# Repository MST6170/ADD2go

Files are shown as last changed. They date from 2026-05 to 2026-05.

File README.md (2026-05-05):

# ADD2go

**Wireless Fernanzeige für Dinamica Generale ADD2 / Siloking Mischwagen**

Überträgt Gewichtsdaten kabellos von der Mischwagen-Waage zum Radlader-Display oder Smartphone.

ADD2go ist in erster Linie eine **Fernanzeige** für die ADD2 Waage. Zusätzlich integriert ist eine **Schaufel-Wiegung** mit Drucksensor — fand ich nützlich, daher ist sie mit reingewandert.

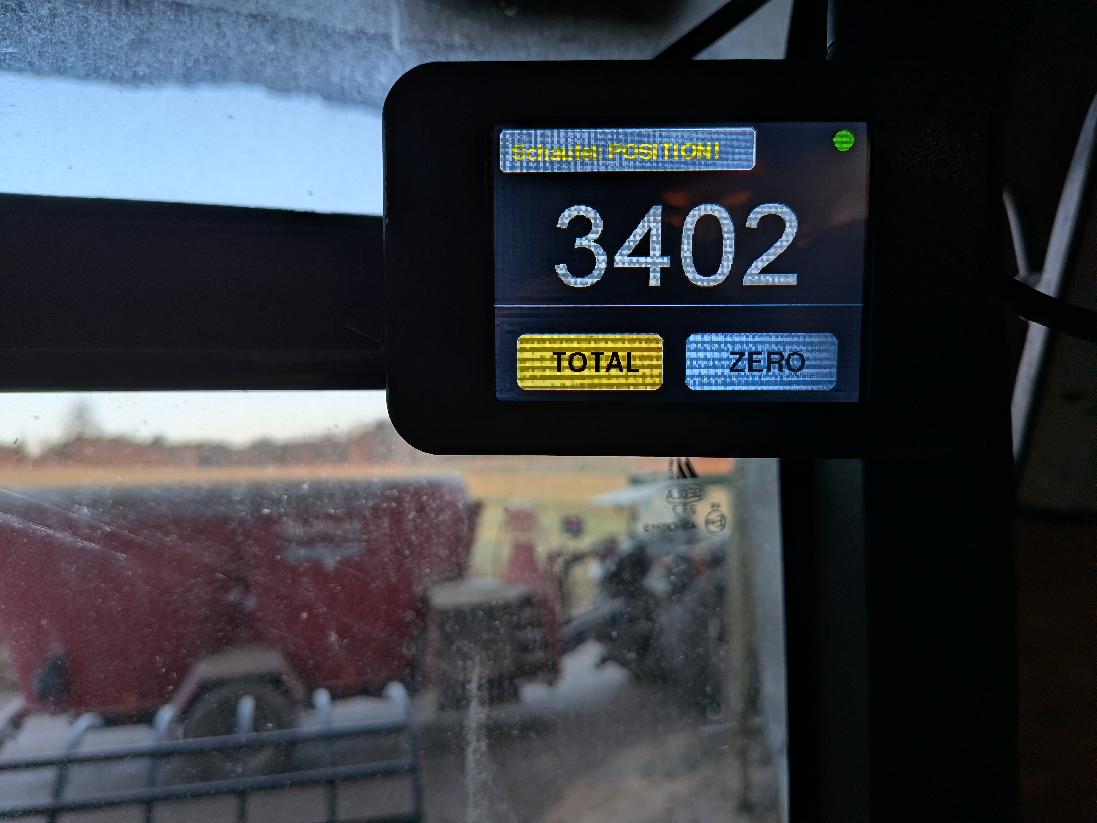
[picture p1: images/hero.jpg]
ADD2go

*ADD2go — kabellose Fernanzeige für die ADD2-Waage*






---

## 📋 Übersicht

ADD2go besteht aus zwei ESP32-Modulen und einer optionalen WebApp:

| Modul | Standort | Funktion |
|---|---|---|
| **Sender** | Mischwagen | Liest RS232 von ADD2 Waage, sendet per WiFi |
| **Empfänger** | Radlader | Zeigt Gewicht auf TFT-Display an |
| **WebApp** | Smartphone | Gewicht im Browser anzeigen |

> 💡 **Hinweis zur Hardware:** Sender und Empfänger nutzen **dieselbe Platine** — sie wird je nach Anwendung unterschiedlich bestückt (Sender: MAX3232 + WI-NET; Empfänger: zusätzlich TFT-Header, ADS1115-Header, K7812M für Drucksensor). Details siehe [`add2go_pcb/README.md`](add2go_pcb/README.md).

### Features

**Sender:**
- ✅ RS232 Auswertung des ADD2 Protokolls
- ✅ WiFi Access Point ("ADD2go")
- ✅ WiFi-Manager - zusätzlich mit Heimnetz verbinden
- ✅ mDNS - erreichbar unter `http://add2go.local`
- ✅ UDP Broadcast für Hardware-Empfänger
- ✅ WebSocket Server für WebApp
- ✅ Eingebaute WebApp mit TOTAL/ZERO Funktion
- ✅ "OFF" Erkennung wenn Waage ausgeschaltet
- ✅ Hardware Watchdog (kein Aufhängen)

**Empfänger:**
- ✅ Echtzeit-Gewichtsanzeige
- ✅ TOTAL/ZERO Funktion (Auto-Reset bei Verbindungsverlust)
- ✅ Schaufel-Wiegung mit Drucksensor (optional)
- ✅ Filter für stabile Anzeige (Mittelwert + Hysterese)
- ✅ ADS1115-Watchdog (Sensor-Ausfall wird erkannt)
- ✅ Auto-Reconnect bei WiFi-Verlust
- ✅ Hardware Watchdog

---

## 🌐 WiFi-Manager

Der Sender kann sich zusätzlich mit einem externen WLAN (z.B. Hof-WLAN) verbinden. Dadurch muss das Handy nicht mehr ins "ADD2go" WLAN wechseln.

### Einrichtung

1. Handy mit WLAN **"ADD2go"** verbinden
2. Browser öffnen: `http://192.168.4.1/setup`
3. Verfügbare Netzwerke werden angezeigt
4. Netzwerk auswählen, Passwort eingeben
5. Nach erfolgreicher Verbindung: erreichbar unter `http://add2go.local`

### Betriebsmodi

| Modus | Beschreibung |
|---|---|
| **Nur AP** | Standard - Sender erstellt eigenes WLAN "ADD2go" |
| **AP + Station** | Sender ist zusätzlich mit Heimnetz verbunden |

### Vorteile der Heimnetz-Verbindung

- Kein WLAN-Wechsel mehr nötig am Handy
- Erreichbar unter `http://add2go.local` (mDNS)
- WLAN-Daten werden gespeichert (überlebt Neustart)
- Auto-Reconnect wenn Mischwagen zurückkommt
- AP "ADD2go" bleibt zusätzlich aktiv (Fallback)

---

## 🔧 Hardware

### Sender (Mischwagen)

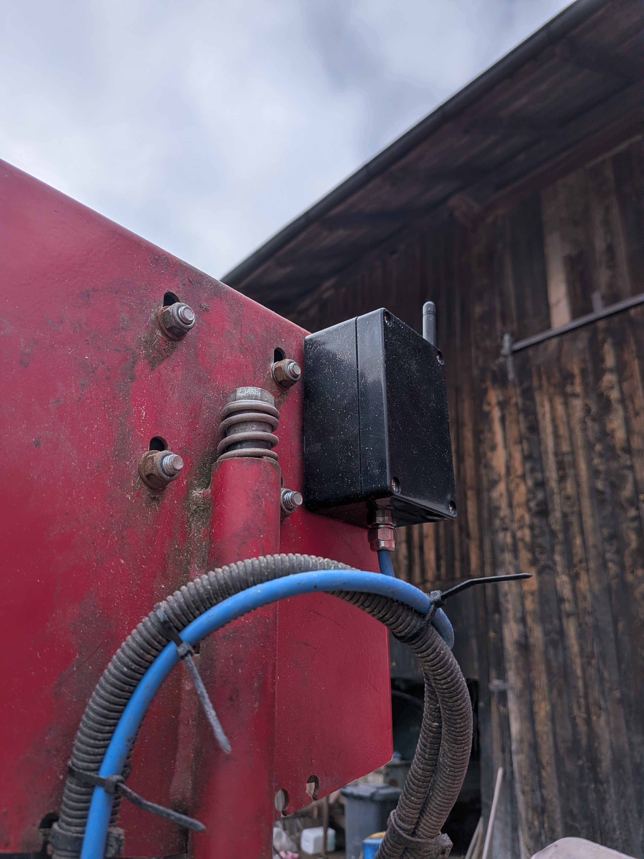
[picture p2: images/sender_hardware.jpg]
Sender-Modul

*Sender-Modul: ESP32, MAX3232 (RS232) und 7805-Spannungsregler*

| Komponente | Typ | Bemerkung |
|---|-----|---|
| Mikrocontroller | [ESP32-WROOM-32U](https://www.amazon.de/dp/B0F65KPWYR) | Mit U.FL Antennenanschluss |
| Antenne | 2.4GHz extern | Im ESP32-Set enthalten |
| RS232 Wandler | MAX3232CPE | DIP-16, 5x 1µF Kondensatoren |
| Spannungsregler | K7805M | 12V → 5V Schaltregler (pin-kompatibel zu 7805, kein Kühlkörper nötig) |
| Verpolschutz | 1N5822 | Schottky-Diode |
| Überspannungsschutz | 1.5KE18A | TVS-Diode 18V |
| WI-NET Stecker | Binder M16 5-pol | Bestellnr. 09 0313 00 05 |
| Gehäuse | [Industrie-Gehäuse 100×68×50 mm](https://de.aliexpress.com/item/1005005622148025.html) | gekauft (kein 3D-Druck nötig) |
| Platine | Custom KiCad-Projekt | Schaltplan, Layout, Fertigung — siehe [`add2go_pcb/README.md`](add2go_pcb/README.md) |

**Pinbelegung Sender:**

| ESP32 Pin | Funktion |
|---|---|
| GPIO16 | RX2 ← MAX3232 (Daten von Waage) |
| GPIO17 | TX2 → MAX3232 (nicht verwendet) |
| 5V | Versorgung vom Spannungsregler |
| GND | Gemeinsame Masse |

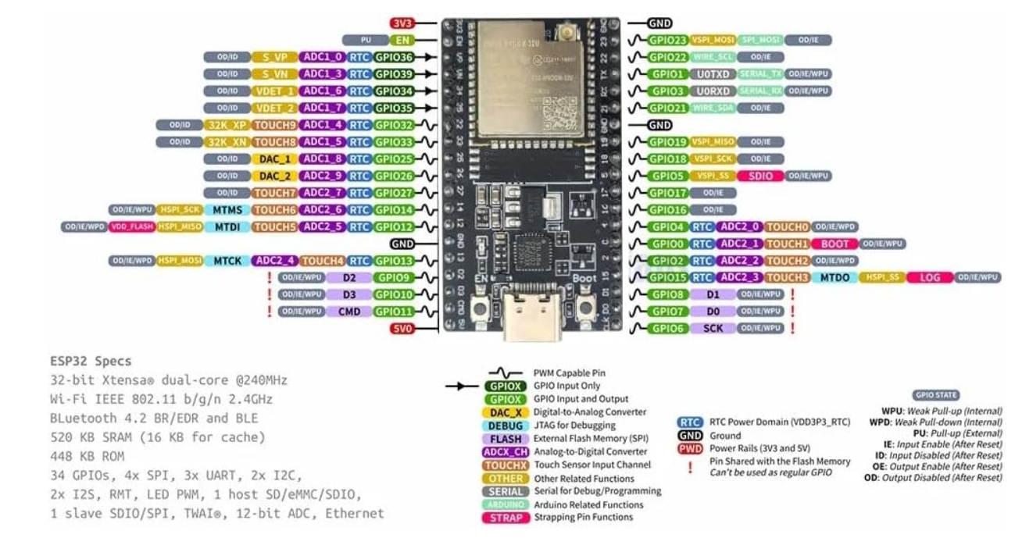
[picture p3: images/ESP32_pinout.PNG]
ESP32 Pinout

*ESP32-WROOM-32 Pinbelegung (Referenz)*

### Empfänger (Radlader)

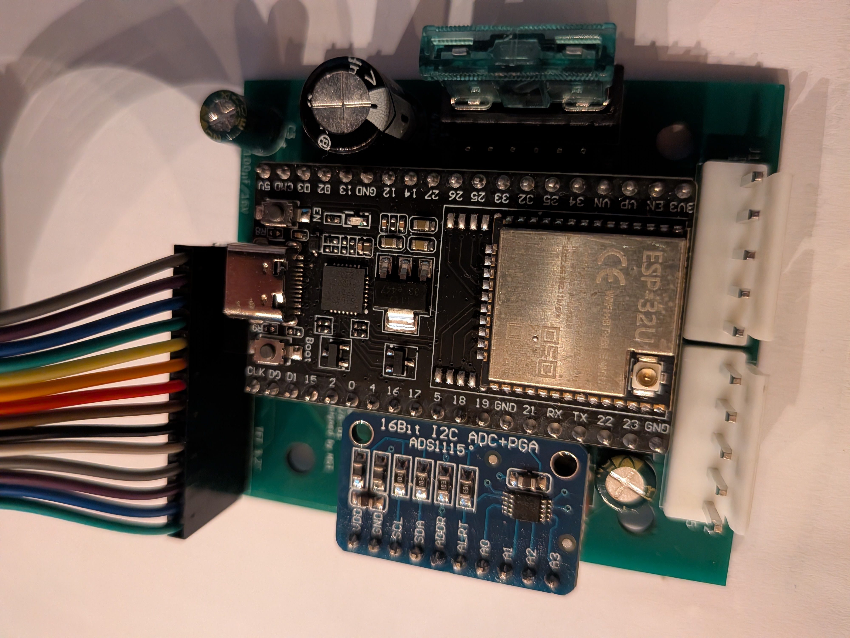
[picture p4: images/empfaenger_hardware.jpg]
Empfänger-Modul

*Empfänger-Modul: ESP32, ILI9341 Display mit Touch und ADS1115 ADC*

| Komponente | Typ | Bemerkung |
|---|-----|---|
| Mikrocontroller | [ESP32-WROOM-32U](https://www.amazon.de/dp/B0F65KPWYR) | Mit U.FL Antennenanschluss |
| Antenne | 2.4GHz extern | Im ESP32-Set enthalten |
| Display | [ILI9341 3.2" TFT](https://de.aliexpress.com/item/1005003005216533.html) | 320x240, SPI, mit Touch |
| Touch | XPT2046 | Resistiv, im Display integriert |
| ADC | ADS1115 | 16-bit, I²C (für Schaufel-Wiegung) |
| Drucksensor | [XIDIBEI 0-300 bar](https://de.aliexpress.com/item/4001002862246.html) | 9-36V Versorgung, 0.5-4.5V Ausgang (für Schaufel-Wiegung, optional) |
| Reed-Kontakt | Digital | Wiegeposition erkennen (optional) |
| Spannungsregler 5 V | K7805M | 12 V → 5 V Schaltregler (für ESP32) |
| Spannungsregler 12 V | K7812M | stabilisierte 12 V (für Drucksensor) |
| Gehäuse | 3D-gedruckt | STL-Dateien, Schalter, Kabelverschraubung — siehe [`case/README.md`](case/README.md) |
| Platine | Custom KiCad-Projekt | Schaltplan, Layout, Fertigung — siehe [`add2go_pcb/README.md`](add2go_pcb/README.md) |

**Pinbelegung Empfänger:**

| ESP32 Pin | Funktion |
|---|---|
| GPIO5 | Display CS |
| GPIO2 | Display RST |
| GPIO4 | Display DC |
| GPIO23 | SPI MOSI |
| GPIO18 | SPI SCK |
| GPIO19 | SPI MISO |
| GPIO15 | Touch CS |
| GPIO14 | Touch IRQ |
| GPIO21 | I²C SDA (ADS1115) |
| GPIO22 | I²C SCL (ADS1115) |
| GPIO36 | Reed-Kontakt (LOW = Wiegeposition) |

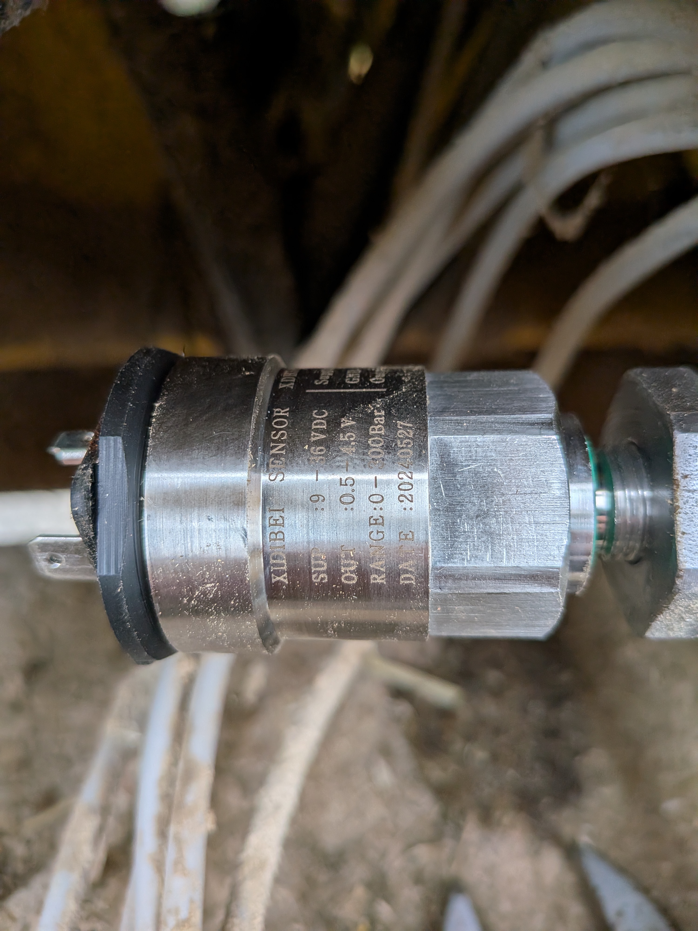
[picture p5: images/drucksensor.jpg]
XIDIBEI Drucksensor

*XIDIBEI Drucksensor (0–300 bar, 9–36 V → 0,5–4,5 V) — Quelle für die Schaufel-Wiegung*

### WI-NET Stecker (ADD2 Waage)

Der WI-NET Anschluss ist ein 5-poliger M16 Stecker an der ADD2 Waage.

**Passender Kabelstecker:** [Binder Serie 680, M16, 5-polig](https://www.binder-connector.de/de/produkte/rundsteckverbinder/m16-ip40-serie-680/kabelstecker-09-0313-00-05)
- Bestellnummer: **09 0313 00 05**
- Lötkontakte, 3.0-6.0mm Kabeldurchlass

> 💡 **Hinweis:** Bei diesem Stecker bin ich mir nicht 100% sicher — er passt nicht ganz exakt in die Buchse, funktioniert aber zuverlässig.

Die Pinbelegung wurde durch eigene Messungen ermittelt:

| Pin | Position | Funktion | Verbindung |
|-----|---|---|---|
| 1 | unten | +12V | → Spannungsregler VIN |
| 2 | rechts oben | GND | → Gemeinsame Masse |
| 3 | oben mitte | TX | → MAX3232 R1IN (Pin 13) |
| 4 | links oben | - | nicht belegt |
| 5 | links unten | - | nicht belegt |

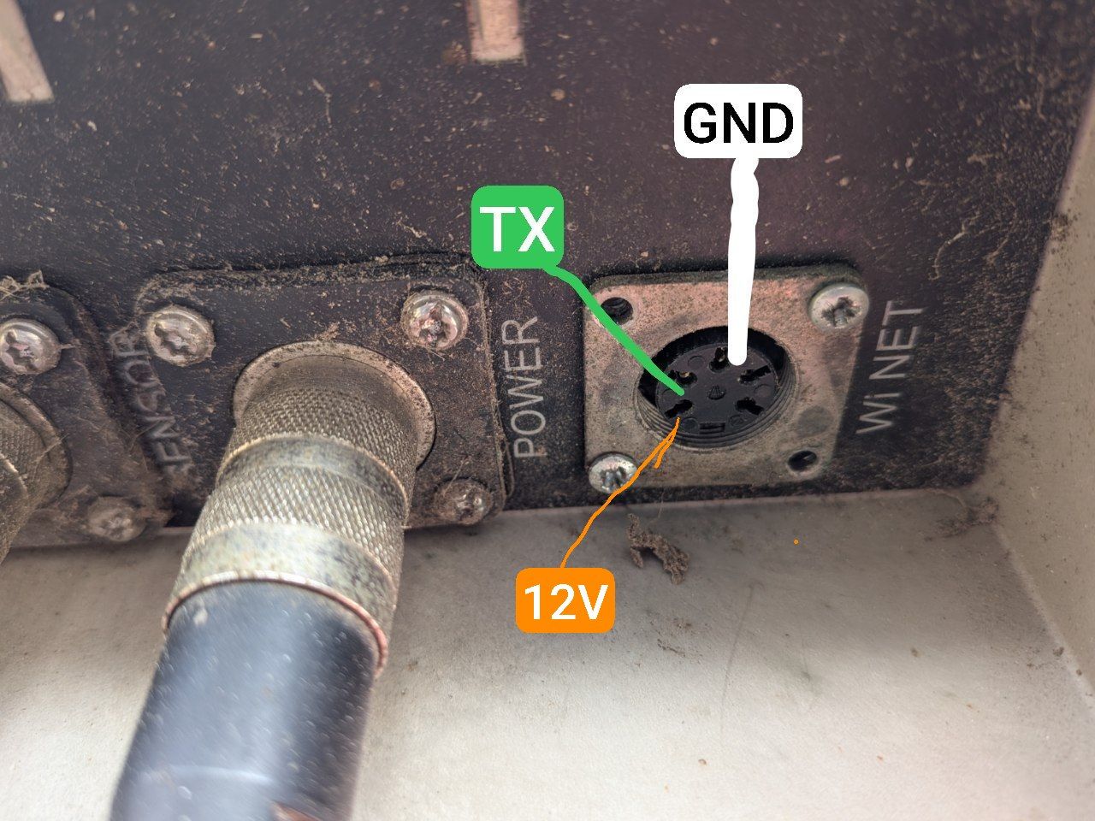
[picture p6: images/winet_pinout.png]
WI-NET Stecker

*WI-NET Stecker (Binder M16, 5-polig) — eigene Messung der Pinbelegung*

> ⚠️ **Wichtig:** Pinbelegung von vorne auf die Buchse (an der Waage) gesehen!

---

## 📡 Kommunikation

### WiFi Konfiguration

| Parameter | Wert |
|---|---|
| AP SSID | `ADD2go` |
| AP Passwort | keins (offen) |
| AP IP | `192.168.4.1` |
| AP Subnetz | `255.255.255.0` |
| mDNS Hostname | `add2go.local` |
| WiFi Modus | APSTA (AP + Station gleichzeitig) |

### Netzwerk-Protokolle

| Protokoll | Port | Richtung | Verwendung |
|---|---|---|---|
| UDP Broadcast | 5005 | Sender → Empfänger | Hardware-Display |
| WebSocket | 81 | Sender ↔ Browser | WebApp (bidirektional) |
| HTTP | 80 | Browser → Sender | WebApp + Setup-Seite |

### UDP Protokoll (für Hardware-Empfänger)

Der Sender sendet alle 100ms (10 Hz) einen UDP-Broadcast:

| Parameter | Wert |
|---|---|
| Ziel-IP | `192.168.4.255` (Broadcast) |
| Port | `5005` |
| Format | ASCII String |

**Nachrichten:**

| Nachricht | Bedeutung |
|---|---|
| `1234` | Gewicht in kg (ohne Einheit) |
| `OFF` | Waage ist ausgeschaltet |

### WebSocket Protokoll (für WebApp)

Der Sender sendet alle 100ms (10 Hz) an alle verbundenen WebSocket-Clients:

| Parameter | Wert |
|---|---|
| Port | `81` |
| Format | `Gewicht\|RSSI` |

**Beispiele:**

| Nachricht | Bedeutung |
|---|---|
| `1234\|-65` | 1234 kg, Signalstärke -65 dBm |
| `OFF\|-70` | Waage aus, Signalstärke -70 dBm |

---

## 📟 RS232 Protokoll (ADD2 Waage)

Das RS232 Protokoll wurde durch eigenes Reverse-Engineering ermittelt.

### Schnittstellenparameter

| Parameter | Wert |
|---|---|
| Baudrate | 19200 |
| Datenbits | 8 |
| Parität | Keine |
| Stoppbits | 1 |
| Updaterate | ~1.3 Hz (alle ~770ms) |

### Frame-Struktur

Die Waage sendet kontinuierlich Frames mit folgendem Aufbau:

```
[Präambel] [Start] [Type] [Seq] [Header] [Gewicht ASCII] [Ende]
    16       0x23   0x03   xx    0x18 0x00    "  1234"     0x0A
```

| Feld | Bytes | Wert | Beschreibung |
|---|---|---|---|
| Präambel | 16 | variabel | Sync-Bytes (werden ignoriert) |
| Start | 1 | `0x23` | Start-Marker (`#`) |
| Type | 1 | `0x03` | Frame-Typ (ETX) |
| Sequence | 1 | `0x00-0xFF` | Laufender Zähler |
| Header | 2 | `0x18 0x00` | Fester Header |
| Gewicht | variabel | ASCII | Rechtsbündig mit Leerzeichen |
| Ende | 1 | `0x0A` | Line Feed (LF) |

### Beispiel-Frame

```
Hex:  23 03 7B 18 00 20 20 20 20 32 0A
      │  │  │  │  │  └──────────┴──┴── "    2" + LF = 2 kg
      │  │  │  └──┴── Header 0x18 0x00
      │  │  └── Sequence 0x7B (123)
      │  └── Type 0x03
      └── Start 0x23
```

### Gewichtswerte

| Anzeige Waage | RS232 Daten | Bedeutung |
|---|---|---|
| `2` | `20 20 20 20 32` | 2 kg |
| `123` | `20 20 31 32 33` | 123 kg |
| `1234` | `20 31 32 33 34` | 1234 kg |
| (aus) | keine Daten | Waage ausgeschaltet |

### OFF-Erkennung

Wenn 3 Sekunden lang keine gültigen RS232-Daten empfangen werden, gilt die Waage als ausgeschaltet. Der Sender sendet dann `"OFF"` über UDP und WebSocket.

---

## 💾 Installation

### Voraussetzungen

- Arduino IDE 1.8.19
- ESP32 Board Package (v3.x empfohlen)
- USB-Treiber für ESP32 (CP2102 oder CH340)

### Benötigte Libraries

**Sender:**
- WebSockets by Markus Sattler (Library Manager: "WebSockets")

**Empfänger:**
- TFT_eSPI by Bodmer
- XPT2046_Touchscreen by Paul Stoffregen
- Adafruit ADS1X15 by Adafruit

### TFT_eSPI Konfiguration

Die TFT_eSPI Library muss für das ILI9341 Display konfiguriert werden.

> ⚠️ **Wichtig:** Die TFT_eSPI Library hat eine **globale** Konfigurationsdatei (`User_Setup.h`). Diese wird von ALLEN Projekten geteilt, die TFT_eSPI verwenden! Wenn du an einem anderen Projekt arbeitest und die Pins änderst, läuft ADD2go nicht mehr — `tft.init()` hängt dann beim Boot ohne Fehlermeldung. **Daher: vor jedem Flashen prüfen, dass `User_Setup.h` zu ADD2go passt.**

**Datei:** `Arduino/libraries/TFT_eSPI/User_Setup.h`

```cpp
// Display-Treiber
#define ILI9341_DRIVER

// Display-Größe
#define TFT_WIDTH  240
#define TFT_HEIGHT 320

// Pin-Definitionen
#define TFT_CS   5
#define TFT_DC   4
#define TFT_RST  2
#define TFT_MOSI 23
#define TFT_SCLK 18
#define TFT_MISO 19

// SPI-Geschwindigkeit
#define SPI_FREQUENCY 40000000

// Touch
#define TOUCH_CS 15
```

### Flashen

**Sender:**
```
Board:     ESP32 Dev Module
Datei:     add2go_sender_v1_2_4/add2go_sender_v1_2_4.ino
Baudrate:  115200
```

**Empfänger:**
```
Board:     ESP32 Dev Module
Datei:     add2go_empfaenger_v1_0_2/add2go_empfaenger_v1_0_2.ino
Baudrate:  115200
```

---

## 🖥️ Bedienung

### Hardware-Display (Empfänger)

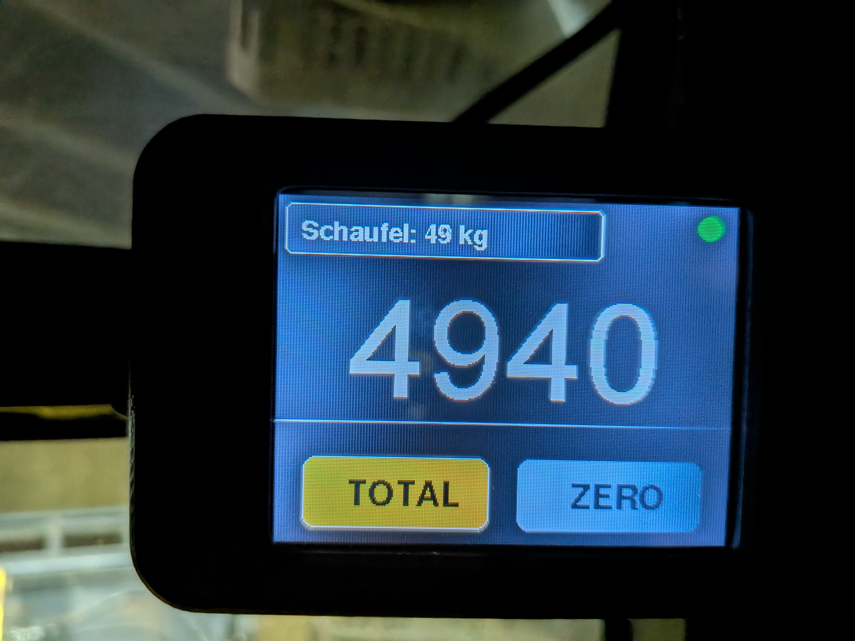
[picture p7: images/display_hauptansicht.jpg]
Display Hauptansicht

*Hauptansicht mit Gewichtszahl und TOTAL/ZERO-Buttons*

**Anzeigen:**

| Anzeige | Farbe | Bedeutung |
|---|---|---|
| Gewicht | Weiß | Normale Anzeige |
| `OFF` | Rot | Waage ausgeschaltet |
| `OFFLINE` | Rot | Keine WiFi-Verbindung zum Sender |
| `SUCHE..` | Orange | WiFi wird gesucht |
| `- - - -` | Grau | Verbunden, warte auf Daten |

**Buttons:**

| Button | Funktion |
|---|---|
| **TOTAL** | Zeigt Gesamt-Gewicht von Waage |
| **ZERO** | Setzt aktuelles Gewicht als Null (Differenz-Messung) |
| **Schaufel** | Öffnet Schaufel-Wiegung Menü |

> 💡 **Hinweis:** ZERO wird automatisch zurückgesetzt wenn die Verbindung zum Sender verloren geht oder die Waage auf OFF wechselt. So gibt es nach Wiedereinschalten keinen falschen Offset.

**Schaufel-Wiegung Menü:**

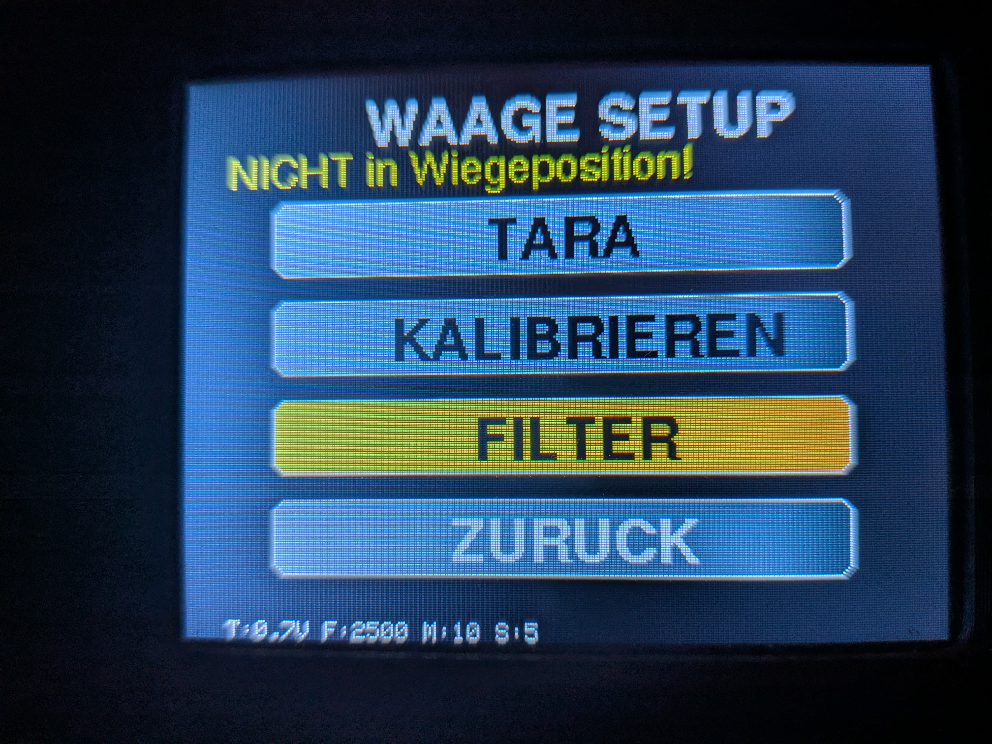
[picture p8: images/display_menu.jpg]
Schaufel-Wiegung Menü

*Setup-Menü für die Schaufel-Wiegung*

| Menüpunkt | Funktion |
|---|---|
| TARA | Setzt leere Schaufel als Nullpunkt |
| KALIBRIEREN | Bekanntes Gewicht eingeben zur Kalibrierung |
| FILTER | Mittelwert-Anzahl (5-30) und Hysterese-Schwelle (1-10 kg) |
| ZURÜCK | Zurück zur Hauptansicht |

> 💡 **Hinweis:** Bei TARA und Kalibrierung wird der Filter-Buffer automatisch geleert, damit die Anzeige sofort die neuen Werte zeigt.

**Sensor-Ausfall:** Wenn der ADS1115 nicht antwortet (z.B. Kabelbruch, Wackelkontakt), zeigt der Schaufel-Button `SENSOR-FEHLER` in rot an. TARA und KALIBRIEREN sind dann gesperrt.

---

## 📱 WebApp

Der Sender bietet eine eingebaute WebApp - das Gewicht direkt auf dem Smartphone anzeigen. Sie funktioniert parallel zum Hardware-Empfänger und ist als Nebenfunktion gedacht.

<p align="center">
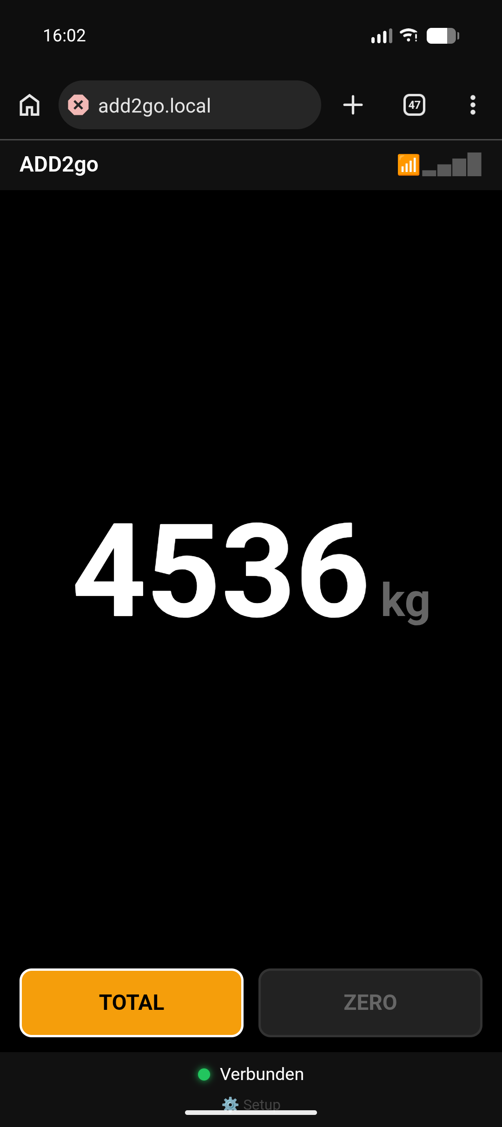
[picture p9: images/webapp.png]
WebApp am Smartphone
  
  <br>
  <em>WebApp im Browser am Smartphone</em>
</p>

### Zugriff

| Methode | URL | Wann nutzen |
|---|-----|---|
| Direkt | `http://192.168.4.1` | Handy mit "ADD2go" WLAN verbunden |
| Heimnetz | `http://add2go.local` | Handy im Hof-WLAN (nach Setup) |
| Heimnetz | `http://[IP-Adresse]` | Falls mDNS nicht funktioniert |

### Funktionen

| Element | Beschreibung |
|---|---|
| **Gewichtsanzeige** | Groß und zentral, mit "kg" Einheit |
| **TOTAL** | Zeigt Gesamtgewicht von der Waage |
| **ZERO** | Speichert aktuelles Gewicht, zeigt Differenz |
| **Signalstärke** | 📶▂▄▆█ (4 Stufen) |
| **Status** | 🟢 Verbunden / 🟠 Waage aus / 🔴 Offline |

### TOTAL / ZERO Funktion

- **TOTAL**: Normaler Modus - zeigt das Gewicht wie es von der Waage kommt
- **ZERO**: Drücken um aktuelles Gewicht als Nullpunkt zu setzen. Danach wird die Differenz angezeigt. Praktisch zum Wiegen von Zuladungen.

Der aktive Modus ist **orange** markiert. Diese Funktion läuft lokal in der WebApp und beeinflusst nicht die ADD2 Waage selbst.

---

## 🔍 Troubleshooting

### Häufige Probleme

| Problem | Ursache | Lösung |
|---|---|---|
| Boot-Loop, hängt bei `tft.init()` | Falsches `User_Setup.h` (z.B. von anderem Projekt überschrieben) | `User_Setup.h` der TFT_eSPI Library prüfen, Pins müssen zu ADD2go passen |
| Display zeigt `OFFLINE` | Kein WiFi zum Sender | Sender einschalten, Nähe prüfen, Antennen prüfen |
| Display zeigt `OFF` | Waage ausgeschaltet | ADD2 Waage einschalten |
| Display zeigt `- - - -` | WiFi ok, aber keine Daten | RS232 Verkabelung prüfen |
| Schaufel: `SENSOR-FEHLER` | ADS1115 antwortet nicht | I²C Verkabelung prüfen, Neustart |
| WebApp zeigt `---` | WebSocket nicht verbunden | Seite neu laden, WLAN prüfen |
| WebApp Buttons grau | Keine Verbindung | Warten oder Seite neu laden |
| `add2go.local` geht nicht | mDNS Problem | IP-Adresse direkt verwenden |
| WLAN-Daten nicht gespeichert | NVS Fehler | Serial Monitor prüfen |
| Sender startet neu | Watchdog | Serial Monitor auf Fehler prüfen |

### Serial Monitor Debug

Baudrate: **115200**

**Sender Startup (normal):**
```
========================================
ADD2go Sender - v1.2.4
========================================

[NVS] Lade gespeicherte Daten...
[NVS] SSID: MeinHofWLAN
[NVS] Passwort: (gespeichert)
[NVS] Auto-Connect: JA
[OK] RS232 gestartet (19200 Baud, GPIO16)
[OK] Watchdog: 10 Sekunden
[OK] WiFi AP gestartet: ADD2go
[OK] AP IP: 192.168.4.1
[STA] Verbinde mit: MeinHofWLAN
....
[STA] Verbunden! IP: 192.168.1.38
[OK] mDNS: http://add2go.local
[OK] UDP Port: 5005
[OK] WebServer gestartet (Port 80)
[OK] WebSocket gestartet (Port 81)

=========== ZUGRIFF ===========
Im ADD2go WLAN:
  WebApp:  http://192.168.4.1
  Setup:   http://192.168.4.1/setup

Im Heimnetz (mDNS):
  WebApp:  http://add2go.local
  Setup:   http://add2go.local/setup
  oder:    http://192.168.1.38
===============================

Warte auf ADD2 Waage...
```

**Sender Betrieb:**
```
[RS232] Gewicht: 1234 kg
[UDP] Gesendet: "1234" (1 AP Clients)
[WS] Client #0 verbunden
[STATUS] AP Clients: 1 | WS Clients: 1 | STA: MeinHofWLAN (192.168.1.38)
```

**Empfänger Startup:**
```
========================================
ADD2go Empfaenger - v1.0.1
========================================

[OK] Reed-Kontakt GPIO36 konfiguriert
[OK] ADS1115 gefunden
[OK] NVS geladen - Tara: 0.500V, Faktor: 100.0 kg/V
[OK] Display initialisiert
[OK] Touch initialisiert
[OK] Watchdog: 5 Sekunden
[OK] WiFi verbunden! IP: 192.168.4.2
[OK] UDP Port: 5005
```

---

## 📁 Projektstruktur

```
ADD2go/
├── add2go_sender_v1_2_4/
│   └── add2go_sender_v1_2_4.ino         # Sender Firmware
├── add2go_empfaenger_v1_0_2/
│   └── add2go_empfaenger_v1_0_2.ino     # Empfänger Firmware
├── add2go_pcb/                           # KiCad-Projekt für die Universal-Platine (Sender / Empfänger)
├── case/                                 # 3D-Druck-STLs für Empfänger-Gehäuse
├── images/                               # Bilder & Pinout-Diagramme
├── User_Setup.h                          # TFT_eSPI-Vorlage (in Library kopieren)
├── CLAUDE.md                             # Kurzdoku für KI-Assistenten
├── README.md                             # Diese Dokumentation
├── LICENSE                               # CC BY-NC-SA 4.0
└── .gitignore                            # Git Ignore-Liste
```

---

## 📜 Changelog

### Sender

#### v1.2.4 (Januar 2026)
- Fix: Watchdog früher initialisieren (vor WLAN-Warteschleife)
- Fix: idle_core_mask konservativer (nur loopTask überwachen)
- Fix: JSON SSID Escaping bei Sonderzeichen

#### v1.2.3 (Januar 2026)
- WebApp: TOTAL/ZERO Buttons hinzugefügt
- WebApp: Gewicht mit "kg" Einheit
- WebApp: Cleaner UI

#### v1.2.2 (Januar 2026)
- mDNS Support (`http://add2go.local`)
- Warten auf WLAN-Verbindung beim Boot (max 15 Sek)
- Bessere Debug-Ausgaben für NVS

#### v1.2.1 (Januar 2026)
- Async WLAN-Scan (verhindert Watchdog-Trigger)
- Robustere loop() mit mehrfachen WDT-Resets
- RS232 Byte-Limit pro Loop (max 256)

#### v1.2.0 (Januar 2026)
- WiFi-Manager WebUI unter `/setup`
- APSTA Modus (AP + Station gleichzeitig)
- WLAN-Daten persistent in NVS gespeichert
- Auto-Reconnect bei Verbindungsverlust

#### v1.1.0 (Januar 2026)
- WebSocket Server für Browser/Handy
- Eingebettete WebApp
- Signalstärke-Anzeige

#### v1.0.0 (Januar 2026)
- Erste stabile Release
- RS232 Protokoll-Auswertung
- UDP Broadcast
- Hardware Watchdog
- OFF-Erkennung

### Empfänger

#### v1.0.2 (Mai 2026)
- NEU: Signalstärke-Anzeige (4 Balken) links vom WiFi-Status-Punkt
- Fix: SENSOR-FEHLER-Anzeige passt jetzt in den Schaufel-Button (zentriert, ohne "Schaufel:"-Präfix)

#### v1.0.1 (Mai 2026)
- Fix: ZERO-Modus wird automatisch zurückgesetzt bei OFF oder Verbindungsverlust
- Fix: Filter-Buffer wird nach TARA/Kalibrierung geleert (verhindert Mischwerte)
- Fix: ADS1115-Watchdog erkennt Sensor-Ausfall und zeigt Warnung
- Fix: Exakte Button-Zentrierung mit `tft.textWidth()`

#### v1.0.0 (Januar 2026)
- Erste stabile Release
- TFT Display mit Touch
- TOTAL/ZERO Funktion
- Schaufel-Wiegung mit ADS1115
- Filter (Mittelwert + Hysterese)
- Hardware Watchdog
- Boot-Screen mit Fortschrittsbalken

---

## ⚠️ Disclaimer

Dieses Projekt ist ein privates DIY-Projekt. Die Verwendung erfolgt auf eigene Gefahr.

- "ADD2", "Dinamica Generale" und "Siloking" sind Marken der jeweiligen Eigentümer
- Das RS232 Protokoll wurde durch eigenes Reverse-Engineering ermittelt
- Keine Garantie auf Funktionalität oder Kompatibilität
- Nicht für sicherheitskritische Anwendungen geeignet
- Änderungen am Fahrzeug können Gewährleistung beeinflussen

---

## 📄 Lizenz



Dieses Projekt ist lizenziert unter [Creative Commons Attribution-NonCommercial-ShareAlike 4.0 International](https://creativecommons.org/licenses/by-nc-sa/4.0/).

**Das bedeutet:**
- ✅ Teilen und Anpassen erlaubt
- ✅ Namensnennung erforderlich
- ❌ Kommerzielle Nutzung verboten
- 🔄 Änderungen müssen unter gleicher Lizenz stehen

---

**Hardware & Software:** MST 2026

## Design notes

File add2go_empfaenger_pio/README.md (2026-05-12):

# add2go-empfaenger-pio

PlatformIO-Migration des **ADD2go-Empfängers v1.0.2** mit Erweiterung um einen
**Flow-Tab** (Phase 3c), der sich per WebSocket-Client mit
[add2flow](https://github.com/MST6170/add2flow) verbindet.

Original-Sketch
[`add2go_empfaenger_v1_0_2.ino`](../add2go_empfaenger_v1_0_2/add2go_empfaenger_v1_0_2.ino)
bleibt im Repo-Root nebendran als **Stable-Backup** unangetastet.

## Hardware

Läuft auf der bestehenden **ADD2go-Empfänger-PCB** v1.0.2 — gleiche Bestückung
wie für den Sketch, kein PCB-Re-Spin.

| Komponente | Anschluss | Notiz |
|---|---|---|
| MCU | ESP32-WROOM-32U | mit externer Antenne |
| Display | ILI9341 SPI 240×320 | CS=5 / RST=2 / DC=4 / MOSI=23 / SCK=18 / MISO=19 |
| Touch | XPT2046 | T_CS=15 / T_IRQ=14 |
| ADC | ADS1115 I²C | SDA=21 / SCL=22 / Addr 0x48 |
| Reed-Kontakt | GPIO36 | LOW = Schaufel in Wiegeposition |

Pin-Map zentral in [include/config.h](include/config.h), Display-Pins zusätzlich
in `platformio.ini` build_flags (TFT_eSPI braucht beide Stellen synchron).

## Build

PlatformIO (`pio`) liegt unter `C:\Users\MST\.platformio\penv\Scripts\`.

```bash
pio run -t upload                                  # default env = main
pio device monitor                                 # 115200, esp32_exception_decoder
pio run -e main -e wifi_test -e display_test -e flow_tab_test   # alle 4 Envs
```

## Phase-Tabelle

| Phase | Komponente | Status |
|---|---|---|
| 3c-1  | Repo-Init + Auto-Push-Hook + gitignore-Setup | ✅ done |
| 3c-2  | PlatformIO-Skelett + 4 Env-Stubs | ✅ done |
| 3c-3  | Sketch-Migration in Module (Spaghetti → Module) | ✅ Code komplett, Display + NVS verifiziert am 2026-05-11 |
| 3c-4  | Tab-Switch-Button (rechts oben, Wassertropfen ↔ ADD2) | ✅ visuell verifiziert |
| 3c-5  | Flow-Tab mit WebSocketsClient + Confirm-Modal + Offline-Greying | ✅ Code komplett + Build grün, mehrere E2E-Befüllungs-Cycles stabil (2026-05-12) |
| 3c-6  | Doku finalisieren | ✅ done |
| 3c-7  | Hotfix: ADD2-Button bleibt sichtbar während FILLING (Liter-fillRect bis x=280 statt 320) | ✅ geflasht 2026-05-12 |

## Doku-Files

| Datei | Zweck |
|---|---|
| [CLAUDE.md](CLAUDE.md) | Architektur-Übersicht für Code-Sessions, Migration-Map |
| [HARDWARE.md](HARDWARE.md) | Pin-Map (entsteht in Schritt 6) |
| [GOTCHAS.md](GOTCHAS.md) | Stolperfallen aus Migration (entsteht in Schritt 6) |
| [USER_FLOWS.md](USER_FLOWS.md) | Menü-Tree + Flow-Tab-State (entsteht in Schritt 6) |
| [REGRESSION_CHECKLIST.md](REGRESSION_CHECKLIST.md) | v1.0.2-Verhaltens-Checkliste, vor jedem Refactor abhaken |

## Repo-Struktur

Dieser PlatformIO-Empfänger lebt als **Unterordner** im bestehenden
`MST6170/ADD2go`-Repo (alles auf `main`). Begründung: alle ADD2go-Artefakte
(Original-Sketch, Sender-Sketch, KiCad-PCB-Daten, 3D-Druck-STL-Cases,
PIO-Migration) bleiben in **einer Git-History**. Versionierung von Hardware
(PCB-Rev) und Firmware (Sketch v1.0.2 → PIO v1.1) wandert mit denselben
Commits.

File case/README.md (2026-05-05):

# ADD2go Empfänger-Gehäuse

## Übersicht

3D-Druck-Gehäuse für den ADD2go-Empfänger im Radlader. Besteht aus
Hauptgehäuse, Deckel mit Display-Ausschnitt sowie einer Kugelgelenk-Halterung
zur Befestigung an einer beliebigen Stelle im Fahrerstand.

## STL-Dateien

| Datei | Funktion |
|---|---|
| `boxv2.stl` | Hauptgehäuse für ADD2go-Platine + ESP32 |
| `deckel v2.stl` | Deckel mit Display-Ausschnitt |
| `anschraubplatte_neu.stl` | Befestigungsplatte zum Anschrauben am Fahrzeug |
| `Ball-joint_mit_bohrung.stl` | Kugelgelenk-Aufnahme (mit Bohrung für die Schraube) |
| `Ball-joint_screwv1.3.stl` | Schrauben-Element des Kugelgelenks |

## Zusätzlich benötigte Hardware

| Bauteil | Typ | Bezugsquelle |
|---|---|---|
| Ein-/Aus-Schalter | im Gehäuse verbaut | [AliExpress](https://de.aliexpress.com/item/4000370543838.html) |
| Kabelverschraubung | PG9 (für Stromzufuhr-Kabel) | [Amazon B0BXWVX9TS](https://www.amazon.de/dp/B0BXWVX9TS) |

## Querverweis

Komponentenliste, Pinbelegung und Setup des Empfängers: siehe
[Haupt-README](../README.md).

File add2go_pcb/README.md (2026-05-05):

# ADD2go PCB

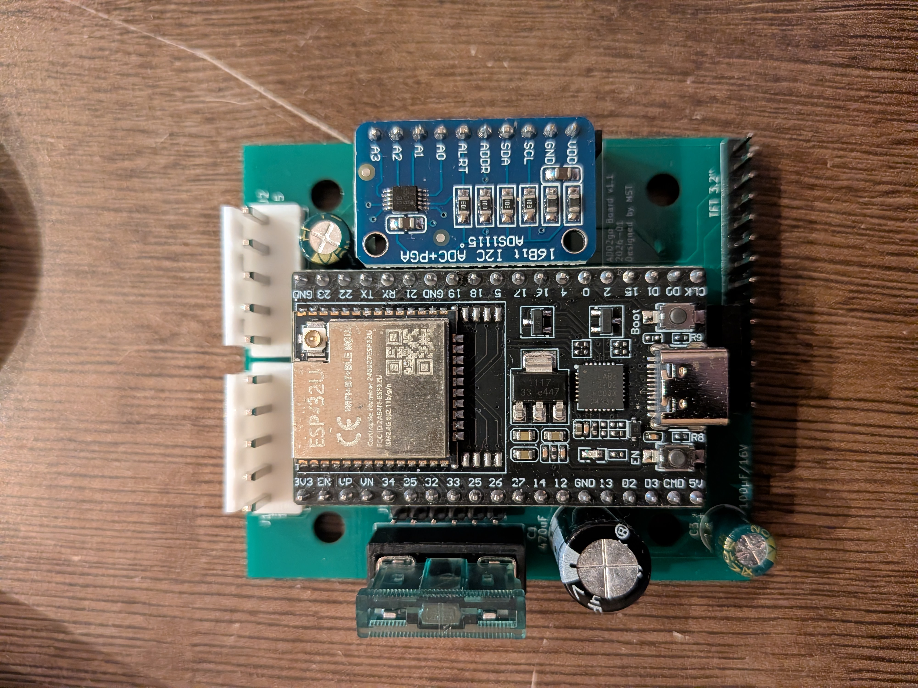
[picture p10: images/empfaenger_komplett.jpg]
Empfänger-Modul komplett

*Fertiges Empfänger-Modul auf Basis dieser Platine*

## Übersicht

Universelle Platine für ADD2go — kann je nach **Bestückung** entweder als
**Sender** (im Mischwagen, Anschluss an die ADD2-Waage über RS232) oder als
**Empfänger** (im Radlader, mit TFT-Display und Drucksensor für die
Schaufel-Wiegung) verwendet werden. Beide Varianten teilen das gleiche Board.

## Status

**Version 1** — bestellt bei JLCPCB, getestet, läuft produktiv.

## Features

- RS232-Pegelwandlung mit MAX3232 (Sender-Bestückung, für die ADD2-Waage)
- 12 V → 5 V Versorgung mit K7805M Schaltregler (für ESP32)
- 12 V stabilisiert mit K7812M (für Drucksensor in Empfänger-Bestückung)
- Verpolschutz mit 1N5822 Schottky-Diode
- TVS-Überspannungsschutz mit 1.5KE18A (18 V)
- Eingangs-Sicherung
- M16-Anschluss zur Waage (5-polig, WI-NET)
- Sockel für ESP32-WROOM-32U
- Header für TFT 3.2" Display (Empfänger-Bestückung)
- Header für ADS1115 ADC-Modul (Empfänger-Bestückung)
- Reine THT-Bestückung (Through-Hole), keine SMD-Bauteile

## Komponenten

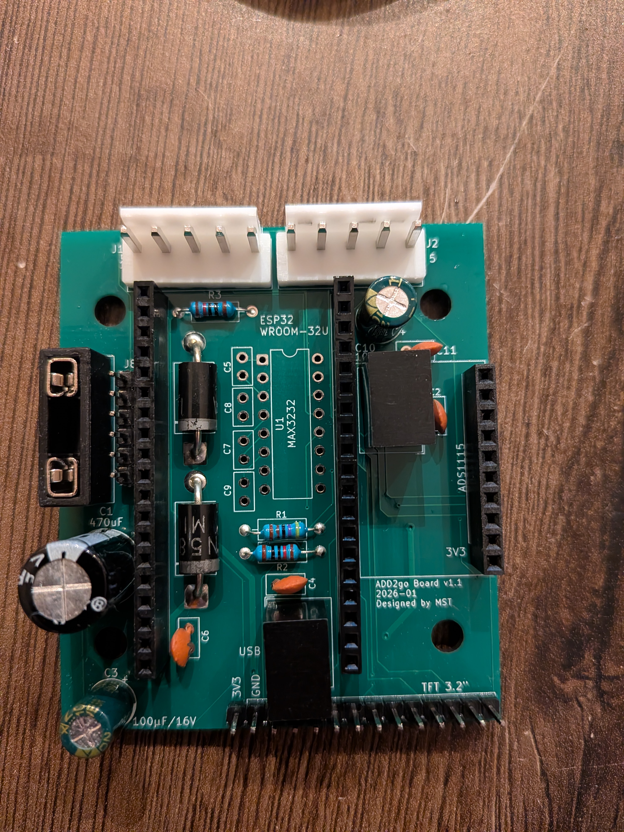
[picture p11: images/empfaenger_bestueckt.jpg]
Bestückte Platine

*Bestückte Platine in Empfänger-Konfiguration*

| Bauteil | Typ | Funktion | Bestückt bei |
|---|---|---|---|
| ESP32-Sockel | Pin-Header 10 + 19 | Modulträger ESP32-WROOM-32U | Sender + Empfänger |
| MAX3232 | Interface-IC | RS232-Pegelwandler | nur Sender |
| K7805M-1000R3 | Mornsun Schaltregler | 12 V → 5 V (~95 % Wirkungsgrad) | Sender + Empfänger |
| K7812M-1000R3 | Mornsun Schaltregler | 12 V stabilisiert (für Drucksensor) | nur Empfänger |
| 1N5822 | Schottky-Diode | Verpolschutz Eingang | Sender + Empfänger |
| 1.5KE18A | TVS-Diode 18 V | Überspannungsschutz | Sender + Empfänger |
| Sicherung | Fuse | Eingangsschutz | Sender + Empfänger |
| Elkos | 100 µF / 16 V, 470 µF | Pufferkondensatoren Versorgung | Sender + Empfänger |
| Kerkos | 100 nF (mehrfach) | MAX3232-Ladekondensatoren + Stützkapazitäten | applikationsabhängig |
| 4k7, 10k | Widerstand | Pull-up / Pull-down | applikationsabhängig |

## Steckverbinder

| Header | Pinzahl | Funktion |
|---|---|---|
| WI-NET (M16) | 5-polig | Anschluss an die ADD2-Waage (Sender) bzw. Versorgung (Empfänger) |
| TFT | 14-polig | ILI9341 3.2" Display + Touch (nur Empfänger-Bestückung) |
| ADS1115 | 6-polig | I²C-Modul für Drucksensor (nur Empfänger-Bestückung) |
| ESP32 | 10 + 19 | Sockel für das ESP32-WROOM-32U-Modul |

> 📌 Pinbelegung des **WI-NET-Steckers** und alle **ESP32-Pin-Zuordnungen** stehen in der [Haupt-README](../README.md).

## Spannungsversorgung

- **Eingang**: 12 V vom WI-NET-Stecker (Bordnetz des Mischwagens / Radladers, real 11–14 V mit Schwankungen)
- Eingangsschutz: Sicherung → TVS (1.5KE18A, 18 V) → 1N5822 Schottky (Verpolschutz)
- **5 V Schiene** (für ESP32): K7805M Schaltregler — kein Kühlkörper nötig (~95 % Wirkungsgrad), weiter Eingangsspannungsbereich, robust gegen Bordnetz-Schwankungen
- **12 V Schiene stabilisiert** (nur Empfänger): K7812M für den XIDIBEI-Drucksensor (9–36 V Versorgungsbereich), liefert sauberere 12 V als das Bordnetz direkt

## Fertigung

| Parameter | Wert |
|---|---|
| Lagen | 2 (F.Cu / B.Cu) |
| Boardgröße | **59 × 68 mm** |
| Boardstärke | 1.6 mm (Standard) |
| Bestückung | reine THT (Through-Hole), manuell |
| Hersteller | bei JLCPCB bestellt |

| Vorderseite | Rückseite |
|---|---|
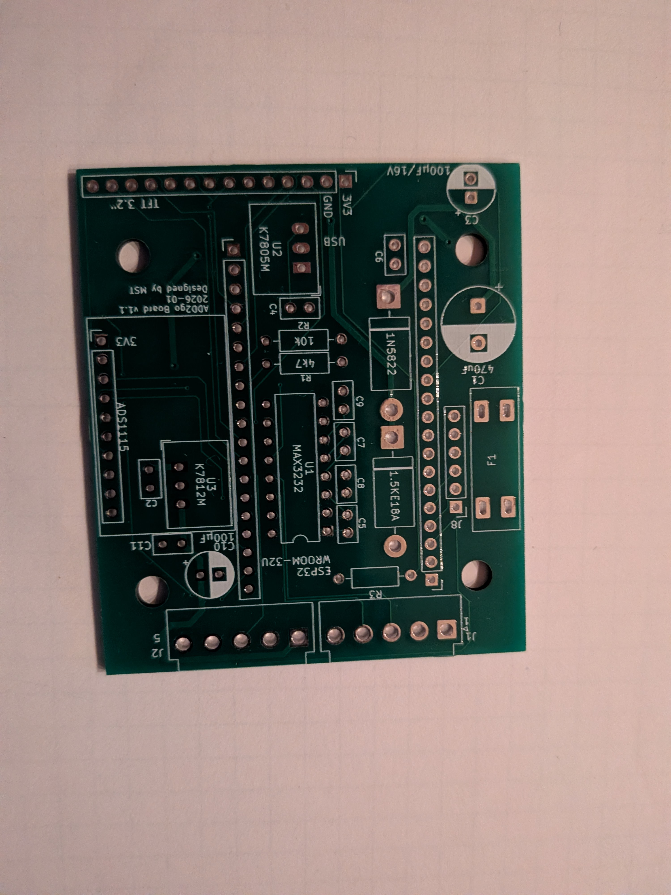
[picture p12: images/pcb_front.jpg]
PCB Front
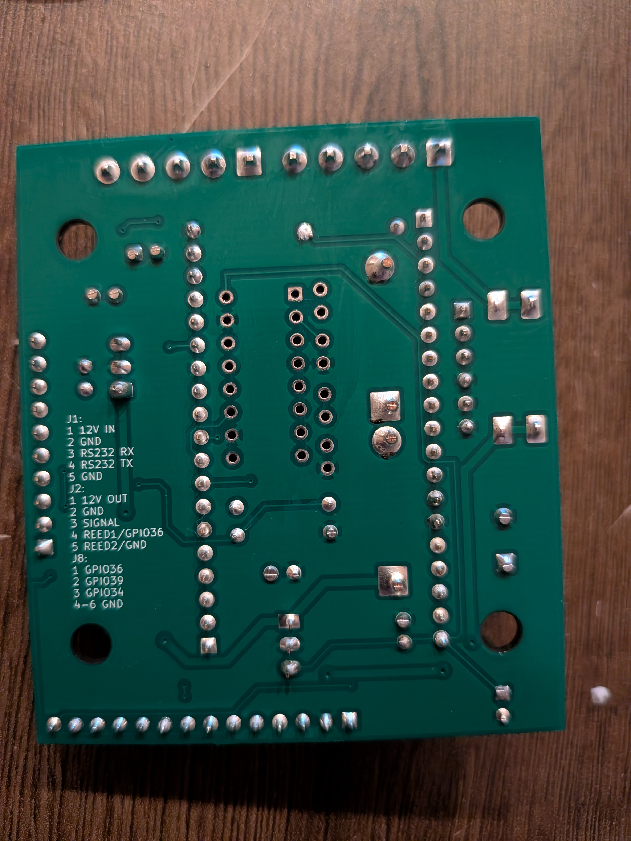
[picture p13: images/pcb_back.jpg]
PCB Back
|  |  |

Gerber- und Drill-Files sind **nicht** im Repo enthalten — bei Bedarf in KiCad über *File → Plot* (Layer F.Cu, B.Cu, F.Mask, B.Mask, F.SilkS, B.SilkS, Edge.Cuts) und *File → Fabrication Outputs → Drill Files* exportieren.

## Dateien im Ordner

| Datei | Bedeutung |
|---|---|
| `add2go_pcb.kicad_pro` | KiCad-Projektdatei (Einstellungen, DRC-Regeln) |
| `add2go_pcb.kicad_sch` | Schaltplan (Eeschema) |
| `add2go_pcb.kicad_pcb` | PCB-Layout (Pcbnew) |

Projekt öffnen mit **KiCad 9.x** über `add2go_pcb.kicad_pro`.

> Hinweis: KiCad legt zusätzlich `*.kicad_prl`-Dateien an — die enthalten lokale User-Einstellungen (zuletzt geöffnete Tabs, Fenster-Layout) und sind über `.gitignore` ausgeschlossen.

## Querverweis

Für den Gesamtkontext (ESP32-Pinbelegung, RS232-Protokoll der ADD2-Waage,
Pinbelegung des WI-NET-Steckers, vollständige Komponentenliste des Projekts):
siehe [Haupt-README](../README.md).

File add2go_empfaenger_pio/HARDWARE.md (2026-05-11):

# Hardware — add2go-empfaenger-pio

1:1 die add2go-Empfänger-PCB v1.0.2. Kein PCB-Re-Spin in Phase 3c.

## ESP32-Modul

**ESP32-WROOM-32U** mit externer Antenne (für besseren Empfang im
Feld-Einsatz unter Blechdach o.ä.). 4 MB Flash, 320 KB RAM.

Bootet auf `esp32dev`-Variante von PlatformIO mit Core 2.0.x (Arduino-Core
Version 3.20014.231204, IDF 4.4.x). Platform gepinnt:
`platform = espressif32 @ ~6.5.0` — siehe [GOTCHAS.md](GOTCHAS.md#core-version-pinnen).

## Pin-Map

| Funktion | GPIO  | Notiz |
|---|---|---|
| Reed-Sensor | 36 | Input-only, LOW = Schaufel in Wiegeposition  |
| I²C SDA | 21 | ADS1115 + spätere I²C-Devices |
| I²C SCL | 22 | ADS1115 + spätere I²C-Devices |
| Display CS | 5 | ILI9341 (240×320) |
| Display RST | 2 | ILI9341 |
| Display DC | 4 | ILI9341 |
| SPI MOSI | 23 | Display + Touch (shared) |
| SPI SCK | 18 | Display + Touch (shared) |
| SPI MISO | 19 | Display + Touch (shared) |
| Touch CS | 15 | XPT2046 |
| Touch IRQ | 14 | XPT2046 (PEN-Down) |
| USB-UART | 1/3 | CP210x via USB-C (TX/RX) |

Pin-Defines zentral in [include/config.h](include/config.h), Display-Pins
zusätzlich in `platformio.ini` build_flags (TFT_eSPI braucht beide Stellen
synchron).

## Sensoren / Peripherie

### ADS1115 (ADC, 16 bit)

I²C-Adresse **0x48** (ADDR-Pin auf GND). Gain `GAIN_ONE` = ±4.096 V FSR.
Single-ended Read auf Kanal 0. Konvertiert die analoge Druckmessdose der
Schaufel.

Watchdog-Logik in [src/scale.cpp](src/scale.cpp):
- 10 aufeinanderfolgende `readADC_SingleEnded == -1` → ADS als ausgefallen
  markiert, Display zeigt „SENSOR-FEHLER!"
- 50 aufeinanderfolgende identische Werte (~5 s) → stuck-Detection,
  ebenfalls SENSOR-FEHLER

### Reed-Kontakt (Position)

GPIO36 (input-only). Reed-Kontakt schliesst gegen GND wenn die Schaufel
in Wiegeposition ist (LOW). Im Loop alle ~10 ms gelesen, sehr
schnelle Reaktion. Bei verlust der Position wird:
- ADC-Sampling pausiert (`schaufelInPosition == false`)
- Wenn gerade im Kalibrieren-/Tara-Confirm-Menü: Rückkehr zum WAAGE-SETUP

### ILI9341 4" SPI TFT 240×320 (Landscape via `setRotation(1)` → 320×240)

TFT_eSPI Library mit `USER_SETUP_LOADED=1`-Override in build_flags (umgeht
globale `User_Setup.h` — kann mit add2flow ST7796 parallel auf demselben
Rechner gebaut werden).

SPI mit 27 MHz, Touch-SPI mit 2.5 MHz. Loaded Fonts: GLCD, 2, 4, 6, 7, 8,
GFXFF (FreeFonts), SmoothFont.

### XPT2046 Resistive Touch (4-wire)

Library: `paulstoffregen/XPT2046_Touchscreen`. Touch-Koordinaten via
`map(p.x, 3900, 300, 0, 320)` und `map(p.y, 3900, 300, 0, 240)` —
Kalibrierungs-Werte aus Sketch v1.0.2 übernommen. Touch-Cal nicht in NVS
persistiert (würde Reset-Knopf brauchen — out of scope für Phase 3c).

## Stromversorgung

USB-C über CP210x-USB-UART → 5 V → 3.3 V LDO am ESP-Modul. ADS1115 und
Display laufen ebenfalls auf 3.3 V. Reed-Kontakt: Pin-INPUT mit internem
Pull-Up.

## Connectoren / Steckplätze

PCB-Schematic siehe [`D:\Add2go\add2go_pcb\add2go_pcb.kicad_sch`](file:///D:/Add2go/add2go_pcb/add2go_pcb.kicad_sch).
KiCad-Daten liegen im Repo-Root des bestehenden ADD2go-Repos
(`MST6170/ADD2go`).

## WiFi-Topologie

Der Empfänger nutzt **zwei** AP-Verbindungen, **eine zur Zeit** (Phase 3c):

| Tab | STA-AP | Protokoll | Use-Case |
|---|---|---|---|
| Schaufel | `ADD2go` | UDP Port 5005 (RX-only)  | Sender-Gewichtsdaten  |
| Flow | `add2flow` | WebSocket Port 81 (RX+TX)| add2flow-Befüllung |

Beim Tab-Switch (`network::onTabChanged()` in [src/network.cpp](src/network.cpp)):
1. `WiFi.disconnect(true)`
2. `WiFi.begin(neuer-AP)`
3. Spinner für max 5 s
4. Bei Timeout → Fallback-Screen mit ADD2-Rück-Button

Restzeit der Verbindung ist non-blocking (`network::handleWiFi()`-Reconnect
alle 5 s).

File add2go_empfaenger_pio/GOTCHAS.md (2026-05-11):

# Gotchas — Stolperfallen beim Arbeiten in add2go-empfaenger-pio

## Core-Version pinnen

`platform = espressif32 @ ~6.5.0` ist **gepinnt** in [platformio.ini](platformio.ini).

ESP32-Arduino-Core ~3.20014 (entspricht Core 2.0.x, IDF 4.4.x) ist die ZWINGENDE Version weil:

- **Watchdog-API**: Der Original-Sketch v1.0.2 nutzt `esp_task_wdt_config_t`-struct-API (IDF 5+). Auf Core 2.0.x existiert die struct-API NICHT — wir nutzen die alte 2-Arg-API `esp_task_wdt_init(WDT_TIMEOUT_SEC, true)` in [src/main.cpp](src/main.cpp). Bei automatischem Bump auf Core 3.x würde **die struct-API erzwungen** (siehe add2flow `GOTCHAS.md`).
- **LEDC-API** (für eventuelle spätere PWM-Erweiterung): gleiches Risiko wie bei add2flow — Core 3.x bricht die Kanal-API.

Wenn `pio platform update` automatisch auf Core 3.x bumpt: **NICHT mergen**. Die `~6.5.0`-Constraint im env greift.

## TFT_eSPI User_Setup.h überschreiben

```ini
build_flags =
    -DUSER_SETUP_LOADED=1
    -DILI9341_DRIVER=1
    -DTFT_WIDTH=240
    -DTFT_HEIGHT=320
    -DTFT_MISO=19 -DTFT_MOSI=23 -DTFT_SCLK=18
    -DTFT_CS=5 -DTFT_DC=4 -DTFT_RST=2
    -DTOUCH_CS=15
    -DLOAD_GLCD -DLOAD_FONT2 ... -DLOAD_GFXFF -DSMOOTH_FONT
```

`USER_SETUP_LOADED=1` schaltet die globale `User_Setup.h`-Inkludierung der
TFT_eSPI-Lib aus, sodass die `build_flags`-Defines greifen. Damit können
add2flow (ST7796 320×480) und add2go-empfaenger-pio (ILI9341 240×320)
parallel auf demselben Rechner gebaut werden ohne sich die globale Config
gegenseitig kaputtzumachen.

**Falle**: Wenn man `User_Setup.h` per Hand aufmacht und dort etwas
ändert, denkt man der Build benutzt die globale Config. Tut er nicht.

## ADS1115-Watchdog (aus Sketch v1.0.1)

Im [src/scale.cpp](src/scale.cpp) sind zwei Schichten:

1. **Fehler-Counter** (`adsFehlerZaehler`): `ads.readADC_SingleEnded` returnt
   `-1` bei I²C-Fehler. Nach 10 Fehlern (= 1 s bei 10 Hz Polling) wird der
   ADS als „nicht vorhanden" markiert.
2. **Stuck-Detection** (`adsGleicheWerteZaehler`): Wenn der Sensor 50×
   identisch denselben Wert liefert (= ~5 s), markiert ihn der Watchdog
   ebenfalls als ausgefallen.

Beide setzen `adsVorhanden = false`, was Display und Logik wissen lässt
„Sensor-Fehler" anzuzeigen statt grottige Werte.

**Falle**: Wenn ein Logic-Bug verhindert dass `adsVorhanden` wieder auf
true gesetzt wird, hilft nur Reboot. Aktuell macht das Sketch und PIO
**nicht** — bewusste Entscheidung, war im Sketch v1.0.2 auch so.

## SPI-Buffer-Konflikt Display vs Touch

Display und Touch teilen den SPI-Bus (MOSI/SCK/MISO). Mit `setRotation(1)`
ist das Display in Landscape. SPI-Frequenz Display: 27 MHz. SPI-Frequenz
Touch: 2.5 MHz (Touch ist langsamer und hat eigenen `SPI_TOUCH_FREQUENCY`).

**Falle**: Bei manchen Boards muss zwischen Display- und Touch-Reads
explizit `SPI.endTransaction()` aufgerufen werden. TFT_eSPI + XPT2046_Touchscreen
machen das aber transparent. Falls Touch-Reads beginnen zu „glitchen":
SPI-Frequenz prüfen.

## Reed-Kontakt nur input-only

GPIO36 ist **input-only** (kein Pull-Up möglich!). Der externe Pull-Up
muss auf der PCB sitzen. Wenn man den ADS abzieht aber den Reed liest,
muss man sicherstellen dass der Pull-Up noch versorgt wird.

## Boot-Loop bei add2flow nicht verfügbar (Phase-3c-spezifisch)

Beim Tab-Switch zu Flow wird `WiFi.disconnect()` + `WiFi.begin("add2flow")`
ausgeführt. Wenn add2flow nicht da ist:

- `WiFi.begin()` ist **non-blocking** — kein Boot-Loop.
- Aber: `WiFi.status()` bleibt `WL_DISCONNECTED`.
- [src/flow_tab.cpp](src/flow_tab.cpp) misst `millis() - s_staSwitchStart`.
  Bei `> WIFI_STA_SWITCH_TIMEOUT_MS` (5 s) → `staSwitchTimedOut() == true`.
- Display zeigt Fallback-Screen mit ADD2-Button rechts oben (zurück zu
  Schaufel-Tab).

**Falle**: Wenn der Spinner unendlich hängt obwohl add2flow nicht da ist,
prüfe ob `displayNeedsFullRedraw` beim Übergang Spinner→Fallback getriggert
wird. In [src/flow_tab.cpp](src/flow_tab.cpp) `loop()` ist eine
Transition-Detection eingebaut die das `displayNeedsFullRedraw = true`
setzt sobald `staSwitchTimedOut()` true wird.

## Auto-Push-Hook und Path-Scoped Stage

Der Auto-Push-Hook in [.claude/auto-push.ps1](.claude/auto-push.ps1) macht
`git -C D:\Add2go add -A add2go_empfaenger_pio/`. **Das `-A`-Flag ist
WICHTIG** für Deletions — bei Modul-Umbenennungen würde sonst die gelöschte
Datei im Remote weiterhin existieren. Das `add2go_empfaenger_pio/` am Ende
verhindert dass parallele Änderungen an Sender-Sketch / KiCad / STL
versehentlich mitcommitted werden.

**Falle**: Wenn jemand `git add -A` ohne Pfad nutzt, werden ALLE
Repo-Änderungen gestaged — auch die Sender-Sketch-Modifikationen. Immer
path-scoped staged.

## WebSocketsClient (Phase 3c) vs WebSocketsServer (add2flow)

`links2004/WebSockets@^2.6.1` — gleiche Lib für beide Seiten. add2flow
nutzt `WebSocketsServer`, der Empfänger im Flow-Tab nutzt
`WebSocketsClient`. Beide haben dasselbe Event-Handler-Pattern.

**Falle**: Nicht beide gleichzeitig in einer Binary instanzieren — das
kostet ~50 kB extra Heap. Im Empfänger nur Client, im add2flow nur Server.

## ESP32-AP-Default-IP-Verwirrung

`192.168.4.1` ist die **Standard-AP-IP** für ESP32-SoftAP. Beide add2flow
**und** add2go-Sender nutzen diese IP für ihren eigenen AP. Heißt: Der
Empfänger, wenn er sich mit „ADD2go" verbindet, bekommt typisch `192.168.4.2`
und routet UDP zum Sender. Wenn er sich mit „add2flow" verbindet, bekommt
er ebenfalls `192.168.4.2` und WS zum add2flow.

**Falle**: Im Serial-Log sieht „IP: 192.168.4.2" beide Male gleich aus —
unterschieden wird nur über die SSID. Bei Debugging immer auch die SSID
loggen.

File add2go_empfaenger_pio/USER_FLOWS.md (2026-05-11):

# User Flows — add2go-empfaenger-pio

ASCII-Diagramme der Bedienung. Referenz für jede UI-Änderung — Touch-Pfade
müssen sich konsistent zu diesem Dokument verhalten.

## Top-Level: Tab-System (Phase 3c)

```
                    ┌────────────────────────────────┐
                    │  Boot                          │
                    │  - I2C + ADS + NVS + Display   │
                    │  - Touch                       │
                    │  - Watchdog 5 s                │
                    │  - WiFi STA -> ADD2go          │
                    └──────────┬─────────────────────┘
                               ▼
                    ┌─────────────────┐
              ┌────►│  TAB_SCHAUFEL   │◄─── Default beim Boot
              │     │  (UDP zu Sender) │
              │     └──────┬──────────┘
              │            │ Tap auf Wassertropfen-Button (oben rechts)
              │            ▼
              │     ┌─────────────────┐
              │     │  STA-Switch     │  Spinner waehrend WiFi connectet
              │     │  zu add2flow    │  Max 5 s timeout
              │     └──┬──────────────┘
              │        │
              │  ┌─────┴────────┐
              │  │ STA verbunden│
              │  ▼              ▼ Timeout
              │ ┌──────────┐  ┌───────────────────┐
              │ │ WS-Client│  │ Fallback-Screen   │
              │ │  aktiv   │  │ "add2flow nicht   │
              │ └────┬─────┘  │  erreichbar"      │
              │      │        └────────┬──────────┘
              │      │                 │ Tap ADD2-Button
              │      │ Tap ADD2-Button │
              │      ▼                 ▼
              └──────┴─────────────────┘
                   (zurueck zu Schaufel)
```

Tab-Switch-Button (quadratisch, ~35×35, oben rechts unter Signal-Bars):

- **TAB_SCHAUFEL aktiv** → Symbol dunkelblauer **Wassertropfen** (Ziel-Symbol = Wechsel zu Flow)
- **TAB_FLOW aktiv** → Text **"ADD" / "2"** rubinrot zweizeilig (Ziel = zurück zu Schaufel)

Klick toggelt + triggert STA-Reconnect via `network::onTabChanged()`.

## Schaufel-Tab — Menü-Tree (1:1 wie v1.0.2)

```
HAUPTBILDSCHIRM (MENU_NONE)
├── Schaufel-Button oben → MENU_SCHAUFEL
├── TOTAL-Button → add2Offset reset, ZeroModus off
└── ZERO-Button  → add2Offset = add2Gewicht, ZeroModus on

MENU_SCHAUFEL "WAAGE SETUP"
├── TARA → MENU_CONFIRM_TARA   (nur wenn schaufelInPosition)
├── KALIBRIEREN → MENU_KALIBRIEREN  (nur wenn schaufelInPosition)
├── FILTER → MENU_FILTER
└── ZURUECK → MENU_NONE

MENU_KALIBRIEREN
├── -10 / +10 → kalibierGewicht +- 10
├── ESC → MENU_SCHAUFEL
└── SAVE → schaufelFaktor = kalibierGewicht / spannung, NVS, resetFilter, MENU_NONE

MENU_FILTER
├── Anzahl -5 / +5 → tempFilterAnzahl
├── Schwelle -1 / +1 → tempFilterSchwelle
├── ESC → MENU_SCHAUFEL
└── SAVE → NVS persist (filterAnz, filterSchw), MENU_NONE

MENU_CONFIRM_TARA
├── ESC → MENU_SCHAUFEL
└── SAVE → schaufelTara = schaufelRohwert, NVS, resetFilter, MENU_NONE
```

**Position-Loss-Protection**: Wenn `schaufelInPosition == false` während
`MENU_KALIBRIEREN` oder `MENU_CONFIRM_TARA`, springt
[src/ui.cpp](src/ui.cpp) `handleMenuLiveUpdate()` zurück nach `MENU_SCHAUFEL`
und triggert Full-Redraw.

## Flow-Tab (Phase 3c, Schritt 5)

```
TAB_FLOW (nach STA-Switch verbunden)
├── Liter gross zentriert: "doneL / targetL"
├── L/min klein
├── State-Badge (Farben nach add2flow State):
│   - IDLE/SETTINGS: grau "BEREIT" / "EINSTELLUNG"
│   - FILLING: orange "BEFUELLT"
│   - PAUSED: gelb "PAUSE"
│   - DONE: gruen "FERTIG"
│   - ERROR: rot "FEHLER"
│   - RESUME_PROMPT: blau "FORTSETZEN?"
│   - CALIBRATING: grau "KALIBRIERUNG"
├── 3 Preset-Buttons (p1, p2, p3 aus WS-Broadcast) → Confirm-Modal
└── STOP-Button → sendet "STOP" via WS

CONFIRM-MODAL (Vollbild-Overlay)
├── "Sind Sie sicher?" + "Tank pruefen!"
├── "Preset N starten?"
├── Ja-Button gruen → sendet "START:N" via WS, Modal weg
└── Abbruch-Button rot → Modal weg, kein WS-Command
```

## Wire-Protokoll (Server -> Client, 10 Hz Broadcast)

Pipe-delimited, **erstes Feld ist Protokoll-Version**:

```
v1|STATE|done|target|lpm|preset|err|rssi|p1|p2|p3
```

Empfänger ignoriert Frames wenn `parts[0] != "v1"`. Bei Phase 3d würde
`v2|...` neue Felder einführen, der Empfänger könnte auf v2-Parser
dispatchen ohne Phase 3c-Build zu brechen.

Felder:
- **STATE**: `IDLE` / `RESUME_PROMPT` / `FILLING` / `PAUSED` / `DONE` / `ABORTED` / `ERROR` / `SETTINGS` / `SETTINGS_ADV` / `CALIBRATING`
- **done/target**: `uint16` Liter
- **lpm**: `float` (1 Nachkommastelle)
- **preset**: `0/1/2/3`
- **err**: leer-String oder Fehlermeldung
- **rssi**: `-128` = STA nicht verbunden, sonst dBm
- **p1/p2/p3**: aktuelle Preset-Mengen aus add2flow-NVS

## Wire-Protokoll (Client -> Server, Commands)

Phase 3c sendet nur diese vom Flow-Tab:

| Command | Bedingung |
|---|---|
| `START:1` | Confirm-Modal Ja, Preset 1 |
| `START:2` | Confirm-Modal Ja, Preset 2 |
| `START:3` | Confirm-Modal Ja, Preset 3 |
| `STOP` | STOP-Button direkt |

Nicht implementiert in Phase 3c (Phone-only über add2flow-WebApp):
`ADJUST:+10` / `ADJUST:-10`, `RESUME:YES` / `RESUME:NO`, `ERROR_DISMISS`,
`DONE_DISMISS`.

## Offline-UX

Wenn `millis() - lastFrameMs > 5000` (kein WS-Frame mehr eingegangen):

- Alle Liter/L/min/Badge-Texte werden **grau** dargestellt
- Hinweiszeile „Verbindung verloren" in rot unter dem State-Badge
- Buttons (Preset/STOP) bleiben sichtbar aber Touch wird ignoriert in
  [src/flow_tab.cpp](src/flow_tab.cpp) `handleTouch()` (early return)

Bei wiederhergestelltem WS-Frame: Greying weg, Buttons wieder aktiv.
Transition triggert `displayNeedsFullRedraw=true` für Re-Render.

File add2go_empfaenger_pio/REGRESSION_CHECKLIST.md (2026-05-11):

# REGRESSION CHECKLIST — v1.0.2 → PIO

Sicherheits-Netz vor und nach dem Spaghetti-zu-Module-Refactor in Phase 3c
Schritt 3. **Vor jedem Modul-Cut den Punkt im Sketch lesen, nach Build-grün
gegen die Hardware durchspielen.**

Quelle: [`../add2go_empfaenger_v1_0_2/add2go_empfaenger_v1_0_2.ino`](../add2go_empfaenger_v1_0_2/add2go_empfaenger_v1_0_2.ino)
(1397 Zeilen). Zeilennummern beziehen sich auf diese Datei.

## Schaufel-Sensorik (ADS1115 + Reed + Filter)

- [ ] **1. Tara setzen + Persistenz** — Schaufel-Menü → „Tara setzen" → ConfirmTara „Ja".
      `prefs.putFloat("tara", ...)` + `resetFilter()` läuft, Anzeige geht auf 0 kg.
      Nach Power-Cycle bleibt Tara-Wert erhalten. (Sketch Z. 195-203 `resetFilter`, Z. 242-247 NVS-Load, Z. 730-770 ConfirmTara-Save-Pfad)

- [ ] **2. Kalibrieren** — Menü „Kalibrieren" → bekanntes Gewicht aufgeben →
      Faktor wird korrekt berechnet (`schaufelFaktor = bekanntesGewicht / spannungsdifferenz`)
      und in NVS gespeichert. (Sketch Z. 245 NVS-Load, Z. 700-730 Kalibrieren-Menu)

- [ ] **3. Filter-Mittelwert** — Filter-Anzahl auf 10 (Standard), Schaufel mit
      konstanter Last → Anzeige glatt ohne 1-kg-Sprünge. (Sketch Z. 562-569
      Mittelwert-Berechnung)

- [ ] **4. Filter-Hysterese** — Filter-Schwelle 5 kg (Standard) → kleine
      Last-Schwankungen <5 kg ändern Anzeige nicht. (Sketch Z. 571-576
      Hysterese-Logik)

- [ ] **5. Filter-Buffer-Reset nach Tara** — Tara setzen während Last drauf →
      Filter-Buffer wird geleert, kein Mischwert aus alter und neuer Tara.
      (Sketch Z. 195-203 `resetFilter`, aufgerufen in ConfirmTara-Save-Pfad)

- [ ] **6. ADS1115-Sensor-Fehler-Erkennung** — Sensor-Adern abziehen → nach 10
      I²C-Fehlern „SENSOR-FEHLER"-Anzeige zentriert im Schaufel-Button.
      (Sketch Z. 521-533 Fehler-Counter, Z. 142-147 ADS_FEHLER_LIMIT=10)

- [ ] **7. ADS1115-Stuck-Detection** — Wenn Sensor 50× identischen Wert
      liefert (~5 s) → ebenfalls SENSOR-FEHLER (eingefroren).
      (Sketch Z. 535-547 Stuck-Detection, Z. 146-148 ADS_STUCK_LIMIT=50)

- [ ] **8. Reed-Kontakt-Position** — Schaufel hochheben (Reed offen) → `schaufelInPosition = false`,
      kein ADC-Sample. Schaufel runter (Reed LOW) → `schaufelInPosition = true`,
      ADC läuft. (Sketch Z. 551 `if (schaufelInPosition)`)

## WiFi & UDP

- [ ] **9. WiFi-Reconnect-Loop** — Sender vom Strom → Empfänger geht in
      `WIFI_SUCHE` (rotes Symbol), versucht alle 5 s neu (non-blocking),
      kommt nach Wiederanschalten zurück in `WIFI_OK`. (Sketch Z. 409-438
      `handleWiFi()`, RECONNECT_INTERVAL=5000)

- [ ] **10. UDP-Empfang** — Sender sendet Gewicht → Empfänger zeigt es auf
      Display, `add2DatenVorhanden = true`, `add2LastData` aktualisiert.
      (Sketch Z. 471-505 `handleUDP()`)

- [ ] **11. ZERO-Auto-Reset (3 Trigger)** — ZERO-Modus wird automatisch
      zurückgesetzt (`add2ZeroModus = false`, `add2Offset = 0`) wenn:
      (a) Waage von ON → OFF (Z. 481-485)
      (b) WiFi-Verbindung verloren (Z. 418-419)
      (c) UDP-Daten-Timeout > 2 s (Z. 499-505)
      (Sketch Z. 205-212 `resetZero()`)

- [ ] **12. UDP-Daten-Timeout** — Sender vom Strom (ohne dass WiFi-Loss eintritt) →
      nach 2 s `TIMEOUT_MS` → `add2DatenVorhanden = false`. (Sketch Z. 499-505)

## Display & UI

- [ ] **13. OFF-Anzeige** — ADD2-Waage OFF (Sender sendet „OFF") → Display
      zeigt „OFF" groß statt Zahl. (Sketch Z. 481-488 OFF-Erkennung, Render
      in `zeichneHauptbildschirm`)

- [ ] **14. Signal-Bars 4-Stufen** — 4 Balken bei RSSI > -50 dBm, 3 bei > -60,
      2 bei > -70, 1 bei > -80, 0 bei <= -80 oder Disconnect. Update ~1 Hz.
      (Sketch Z. 583-593 `handleRSSI()`)

- [ ] **15. Boot-Screen mit Fortschrittsbalken** — Power-On → ADD2go-Titel
      groß zentriert + Fortschrittsbalken, dann Übergang zum Hauptbildschirm.
      (Sketch Z. 279-370 Boot-Screen-Sequenz)

- [ ] **16. Menü-Navigation** — Hauptbildschirm → Schaufel-Menu → Kalibrieren /
      Filter / Tara-Confirm. Back-Button funktioniert. Im Menü zeigt
      `handleMenuLiveUpdate` live ADC-Werte. (Sketch Z. 597-620 Live-Update,
      Z. 621-868 Touch-Handler pro Menü)

- [ ] **17. Partial-Redraw-State-Tracking** — Display flackert nicht — Werte
      werden nur neu gezeichnet wenn sie sich ändern (`lastAdd2Anzeige`,
      `lastSchaufelGewicht`, etc.). (Sketch Z. 180-188 State-Tracking-Vars)

## Boot & System

- [ ] **18. Watchdog 5 s** — Mit Sketch-Code soll der Watchdog 5 s sein und
      während Boot-Phase + WiFi-Connect-Loop explizit gefeedet werden.
      (Sketch Z. 113 WATCHDOG_TIMEOUT_SEC=5, Z. 411 `esp_task_wdt_reset` in
      `handleWiFi`, Z. 451 in `verbindeWiFi`)

- [ ] **19. NVS-Load mit Defaults + Limits** — `filterAnzahl` zwischen 5..30,
      `filterSchwelle` zwischen 1..10. Defaults wenn NVS leer. (Sketch
      Z. 246-253)

## Hinweis zum Ablauf

1. Sketch v1.0.2 unflashed lassen, **nur PIO-Build flashen** in Schritt 3.
2. Hardware-Test pro Punkt durchspielen, abhaken.
3. Bei Regression: in `D:\Add2go\add2go_empfaenger_v1_0_2\` zurück, Sketch
   flashen, gegen-testen ob es im Sketch noch geht (Bisect: ist's Migration
   oder schon im v1.0.2 broken?).
4. Punkte als „failed" markieren statt zu löschen — für künftige Refactors
   archivieren.

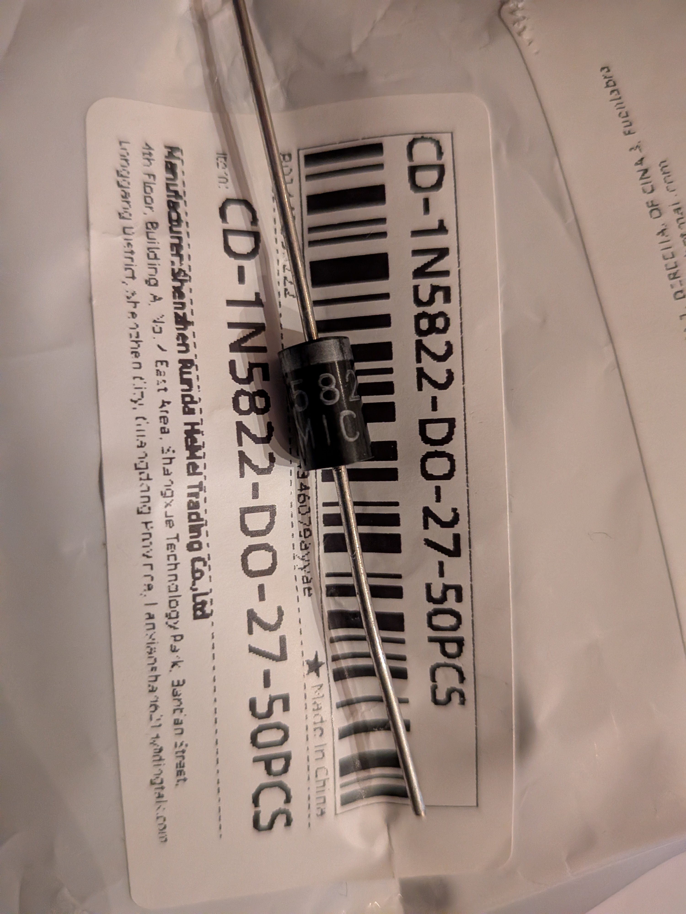
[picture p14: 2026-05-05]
images/PXL_20260502_185916483.MP.jpg

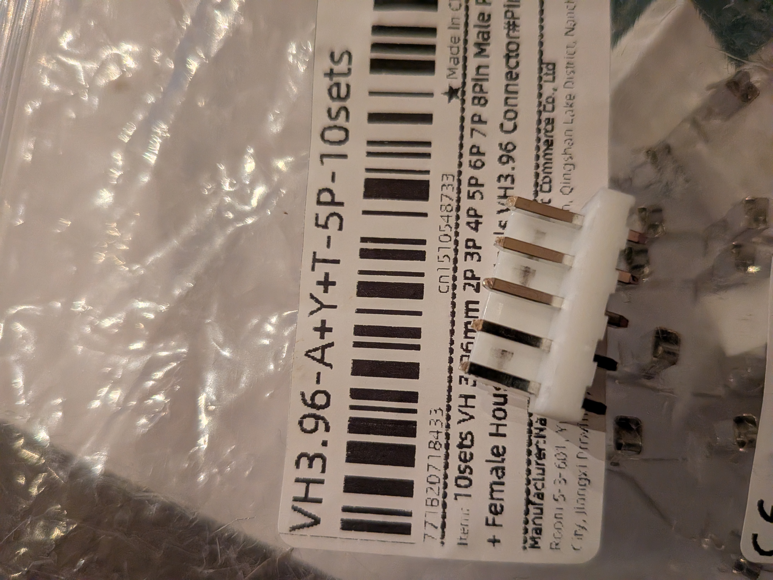
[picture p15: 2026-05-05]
images/PXL_20260502_185654277.MP.jpg

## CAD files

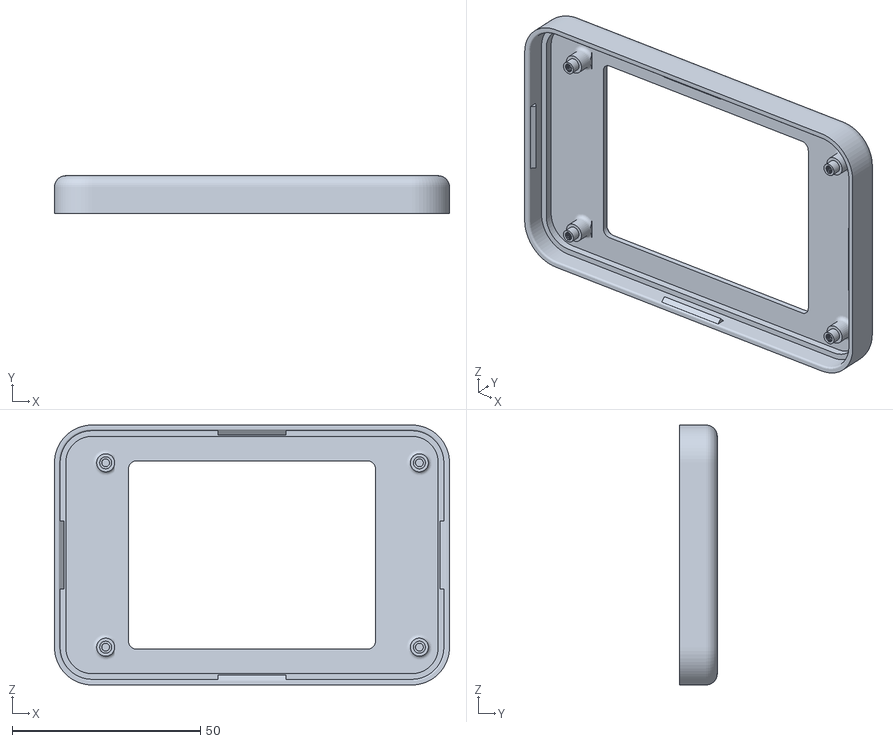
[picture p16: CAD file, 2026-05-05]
case/deckel v2.stl
105.0 x 10.0 x 69.1

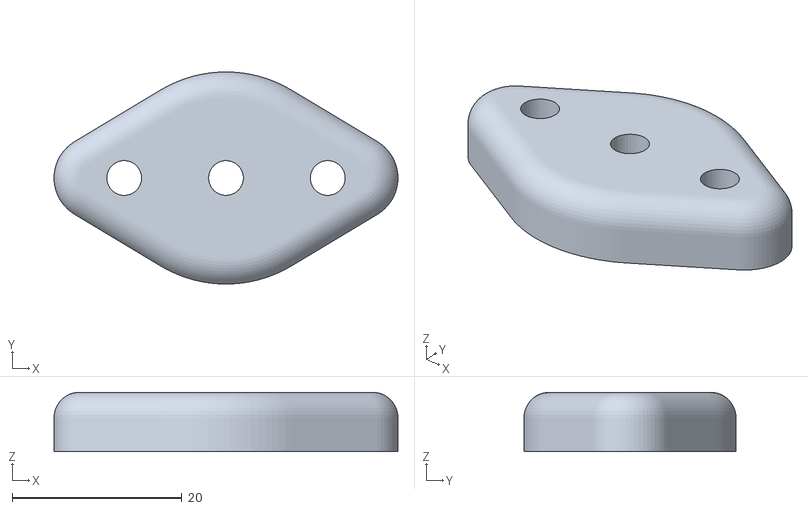
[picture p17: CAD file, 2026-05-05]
case/anschraubplatte_neu.stl
40.6 x 25.0 x 7.00

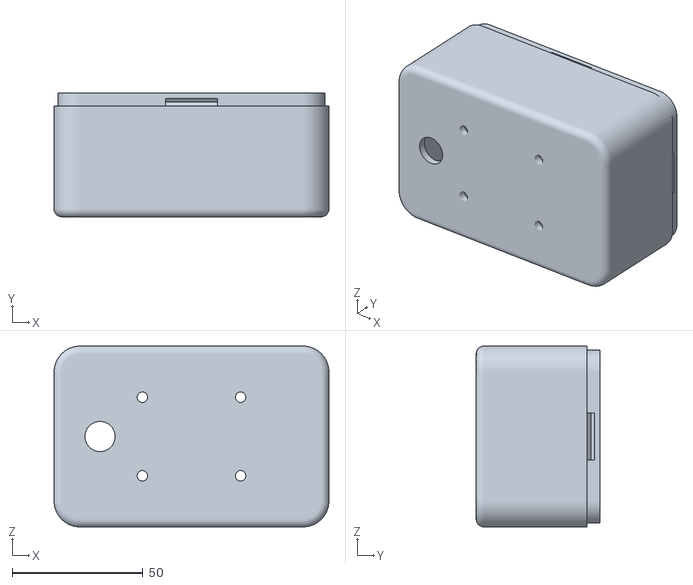
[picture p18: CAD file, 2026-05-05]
case/boxv2.stl
105.0 x 47.2 x 69.1

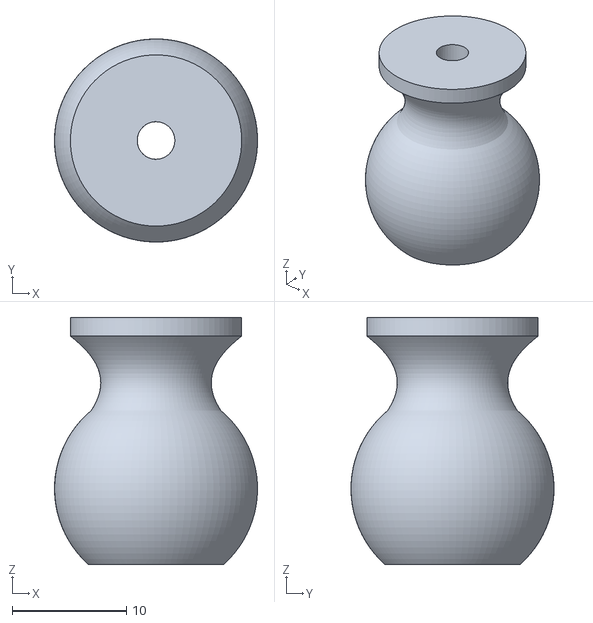
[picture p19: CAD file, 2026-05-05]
case/Ball-joint_mit_bohrung.stl
17.8 x 17.8 x 21.6

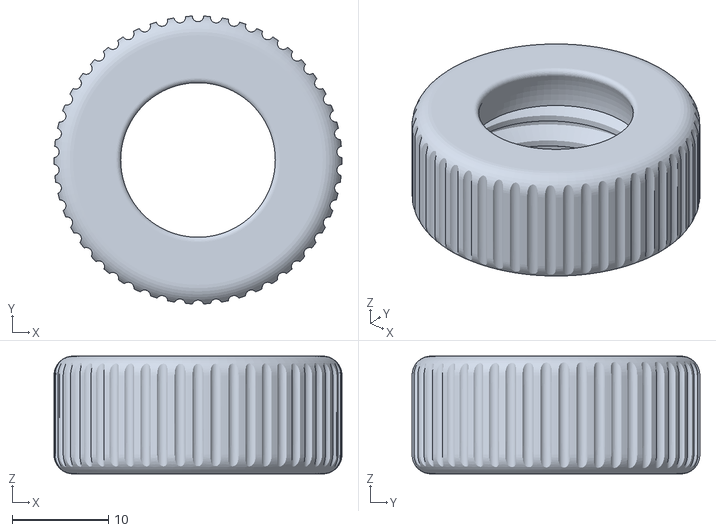
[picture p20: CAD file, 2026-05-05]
case/Ball-joint_screwv1.3.stl
30.0 x 30.0 x 12.3

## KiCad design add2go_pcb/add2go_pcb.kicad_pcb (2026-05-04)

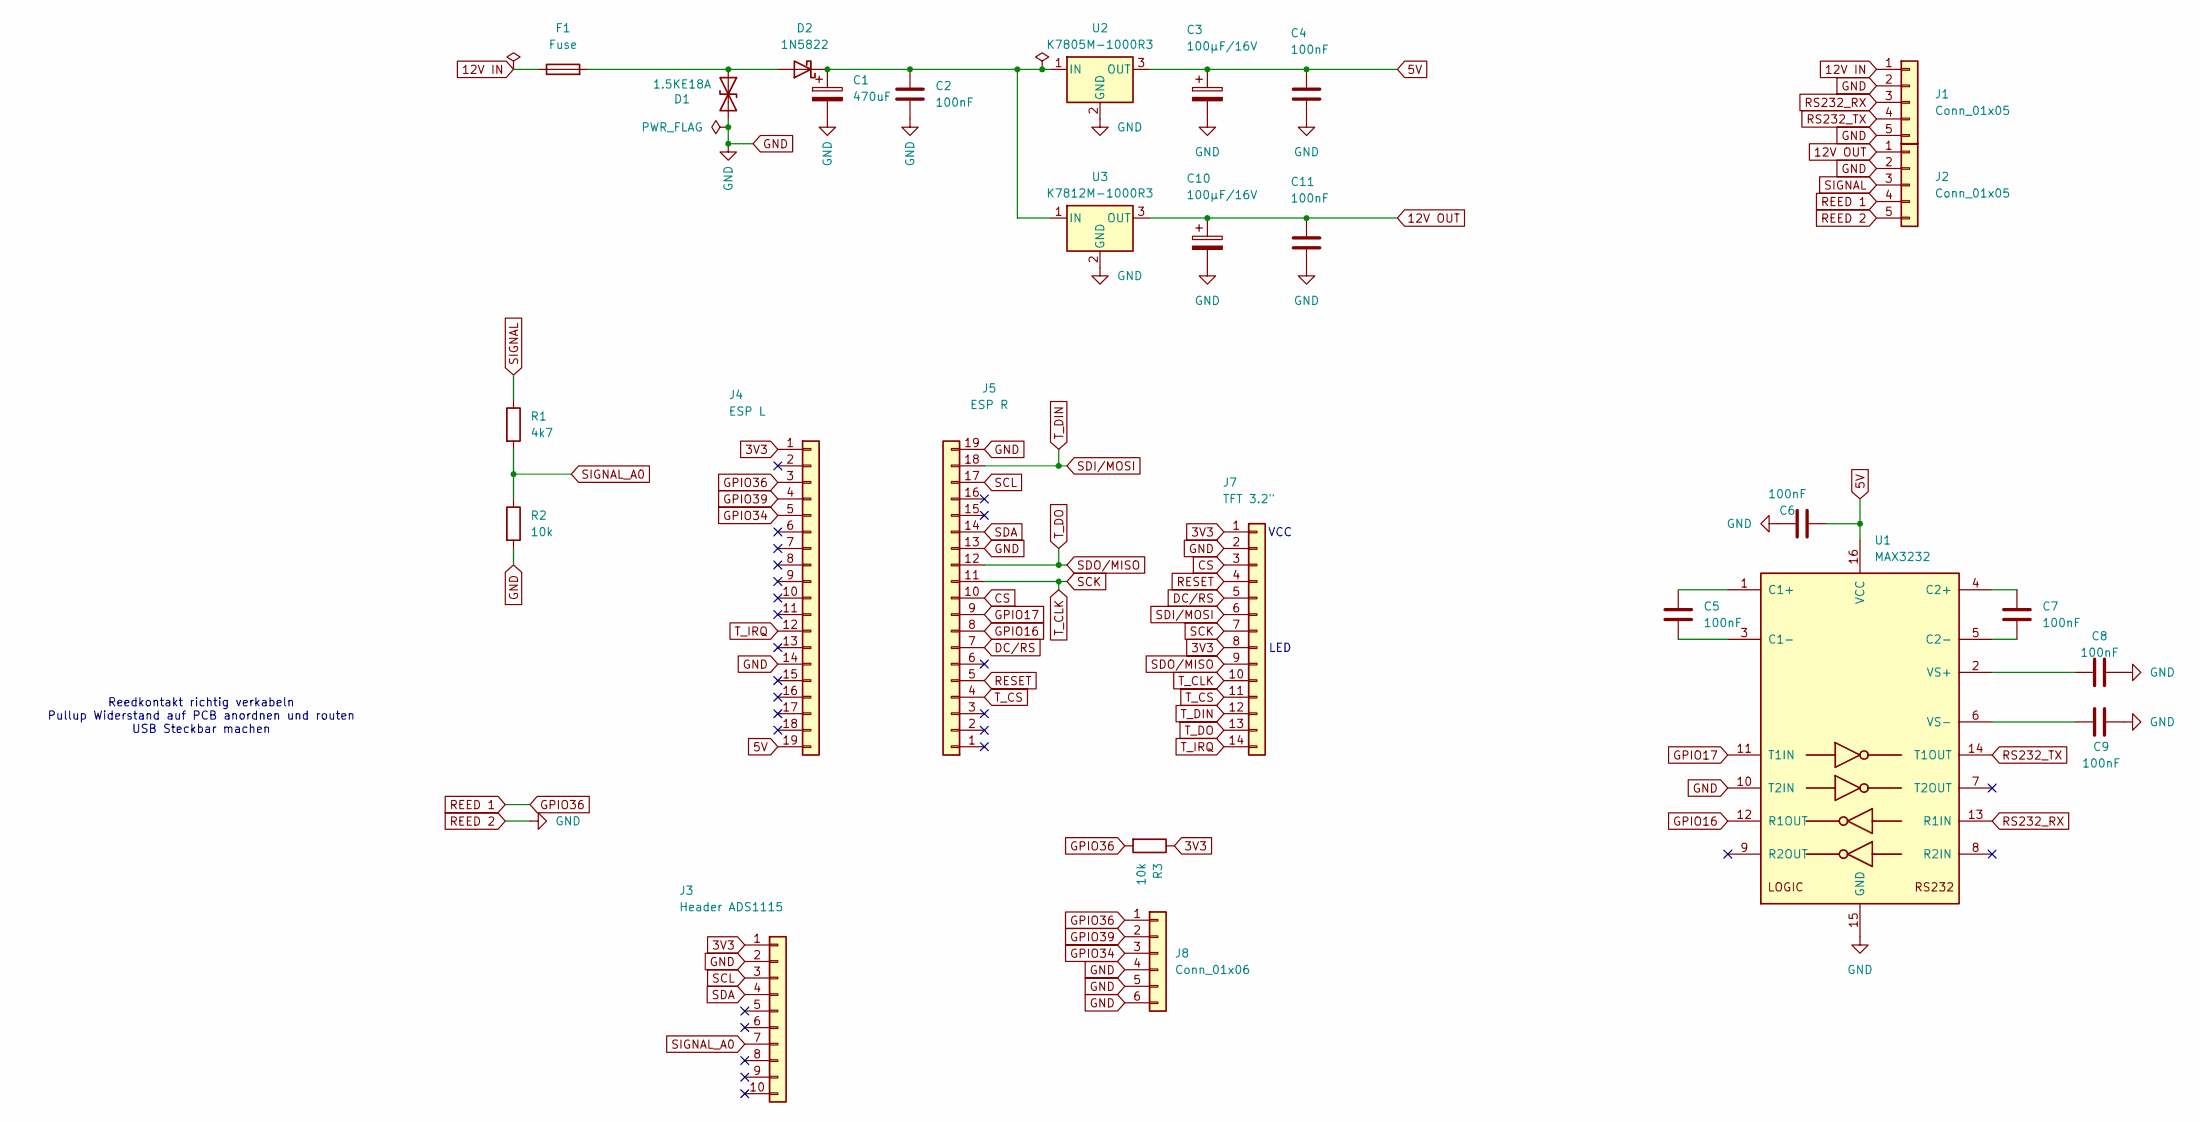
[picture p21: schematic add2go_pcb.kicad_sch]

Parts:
C1: 470uF; CP_Radial_D10.0mm_P5.00mm
C2, C4, C5, C6, C7, C8, C9, C11: 100nF; C_Disc_D5.0mm_W2.5mm_P2.50mm
C3, C10: 100µF/16V; CP_Radial_D6.3mm_P2.50mm
D1: 1.5KE18A; D_DO-201AD_P15.24mm_Horizontal
D2: 1N5822; D_DO-201AD_P15.24mm_Horizontal
F1: Fuse; FuseHolder_ATO_20mm_THT_2x2
J1, J2: Conn_01x05; JST_VH_B5P-VH_1x05_P3.96mm_Vertical
J3: Header ADS1115; PinHeader_1x10_P2.54mm_Vertical
J4: ESP L; PinHeader_1x19_P2.54mm_Vertical
J5: ESP R; PinHeader_1x19_P2.54mm_Vertical
J7: TFT 3.2"; PinHeader_1x14_P2.54mm_Vertical
J8: Conn_01x06; PinHeader_1x06_P2.54mm_Vertical
R1: 4k7; R_Axial_DIN0207_L6.3mm_D2.5mm_P10.16mm_Horizontal
R2, R3: 10k; R_Axial_DIN0207_L6.3mm_D2.5mm_P10.16mm_Horizontal
U1: MAX3232; DIP-16_W7.62mm
U2: K7805M-1000R3; Converter_DCDC_RECOM_R-78E-0.5_THT; LCSC C5279984
U3: K7812M-1000R3; Converter_DCDC_RECOM_R-78E-0.5_THT; LCSC C5279984

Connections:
3V3: J3.1, J4.1, J7.1, J7.8, R3.1
5V: C3.1, C4.1, C6.1, J4.19, U1.16 (VCC), U2.3 (OUT)
12V IN: F1.1, J1.1
12V OUT: C10.1, C11.1, J2.1, U3.3 (OUT)
CS: J5.10, J7.3
DC/RS: J5.7, J7.5
GND: C1.2, C2.2, C3.2, C4.2, C6.2, C8.2, C9.2, C10.2, C11.2, D1.2 (A2), J1.2, J1.5, J2.2, J2.5, J3.2, J4.14, J5.13, J5.19, J7.2, J8.4, J8.5, J8.6, R2.2, U1.10 (T2IN), U1.15 (GND), U2.2 (GND), U3.2 (GND)
GPIO16: J5.8, U1.12 (R1OUT)
GPIO17: J5.9, U1.11 (T1IN)
GPIO34: J4.5, J8.3
GPIO36: J2.4, J4.3, J8.1, R3.2
GPIO39: J4.4, J8.2
unnamed: D1.1 (A1), D2.2 (A), F1.2
unnamed: C1.1, C2.1, D2.1 (K), U2.1 (IN), U3.1 (IN)
unnamed: C5.1, U1.1 (C1+)
unnamed: C5.2, U1.3 (C1-)
unnamed: C7.1, U1.4 (C2+)
unnamed: C7.2, U1.5 (C2-)
unnamed: C8.1, U1.2 (VS+)
unnamed: C9.1, U1.6 (VS-)
RESET: J5.5, J7.4
RS232_RX: J1.3, U1.13 (R1IN)
RS232_TX: J1.4, U1.14 (T1OUT)
SCK: J5.11, J7.7, J7.10
SCL: J3.3, J5.17
SDA: J3.4, J5.14
SDI/MOSI: J5.18, J7.6, J7.12
SDO/MISO: J5.12, J7.9, J7.13
SIGNAL: J2.3, R1.1
SIGNAL_A0: J3.7, R1.2, R2.1
T_CS: J5.4, J7.11
T_IRQ: J4.12, J7.14

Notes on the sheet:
LED
Reedkontakt richtig verkabeln Pullup Widerstand auf PCB anordnen und routen USB Steckbar machen
VCC

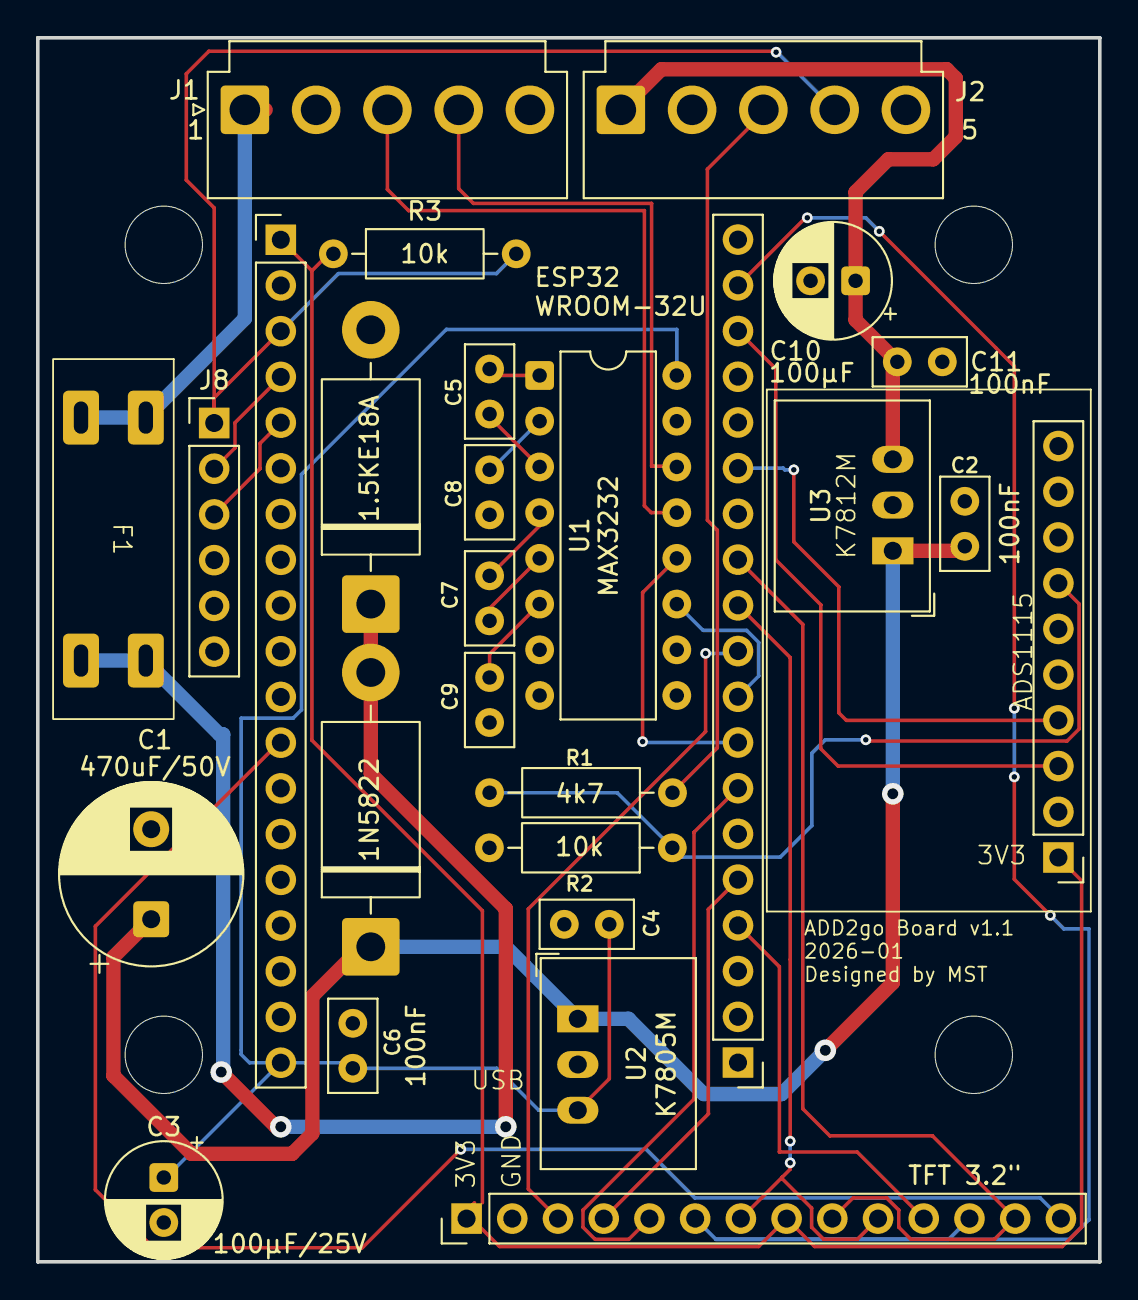
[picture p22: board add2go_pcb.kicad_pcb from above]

Board: 2 copper layers, 59.0 x 68.0 mm, 27 parts (0 on the bottom side), 32 nets.

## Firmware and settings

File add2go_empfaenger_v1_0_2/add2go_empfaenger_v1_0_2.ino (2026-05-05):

/*
 * ADD2go Empfänger - v1.0.2
 * =========================
 * 
 * Wireless Waagen-Display für Dinamica Generale ADD2 Waage
 * Empfängt Gewichtsdaten vom Sender per WiFi/UDP
 * 
 * Features:
 * - ADD2 Gewichtsanzeige (TOTAL/ZERO Funktion)
 * - Schaufel-Wiegung mit Drucksensor (optional)
 * - Filter (Mittelwert + Hysterese)
 * - "OFF" Anzeige wenn Waage aus
 * - Auto-Reconnect bei WiFi-Verlust
 * - Hardware Watchdog (5 Sekunden)
 * - Boot-Screen mit Fortschrittsbalken
 * 
 * Changelog v1.0.2:
 * - NEU: Signalstärke-Anzeige (4 Balken) auf dem Hauptbildschirm
 * - Fix: SENSOR-FEHLER-Anzeige passt jetzt in den Schaufel-Button (zentriert)
 *
 * Changelog v1.0.1:
 * - Fix: ZERO-Modus wird automatisch zurückgesetzt bei OFF oder Reconnect
 *        (verhindert falschen Offset nach Wiedereinschalten der Waage)
 * - Fix: Filter-Buffer wird nach TARA-Save geleert
 *        (verhindert Mischwerte aus alter und neuer Tara)
 * - Fix: ADS1115-Watchdog - bei wiederholten Lesefehlern wird der Sensor
 *        als ausgefallen markiert (für robusten Feldeinsatz)
 * - Fix: tft.textWidth() statt strlen()*14 für exakte Button-Zentrierung
 * 
 * Hardware:
 * - ESP32-WROOM-32U mit externer Antenne
 * - ILI9341 Display: CS=5, RST=2, DC=4, MOSI=23, SCK=18, MISO=19
 * - XPT2046 Touch: T_CS=15, T_IRQ=14
 * - ADS1115 ADC: SDA=21, SCL=22, Adresse 0x48
 * - Reed-Kontakt: GPIO36 (LOW = Wiegeposition)
 * 
 * WiFi: Verbindet sich mit "ADD2go" Access Point vom Sender
 * UDP Port: 5005
 * 
 * (c) MST 2026
 */

#include <WiFi.h>
#include <WiFiUdp.h>
#include <SPI.h>
#include <Wire.h>
#include <TFT_eSPI.h>
#include <XPT2046_Touchscreen.h>
#include <Adafruit_ADS1X15.h>
#include <Preferences.h>
#include <esp_task_wdt.h>

// ============================================
// OBJEKTE
// ============================================
TFT_eSPI tft = TFT_eSPI();
XPT2046_Touchscreen ts(15, 14);
Adafruit_ADS1115 ads;
Preferences prefs;
WiFiUDP udp;

// ============================================
// PINS
// ============================================
#define REED_SENSOR_PIN 36  // Reed-Kontakt für Wiegeposition

// ============================================
// WIFI
// ============================================
const char* WIFI_SSID = "ADD2go";
const char* WIFI_PASS = "";
const int UDP_PORT = 5005;
char udpBuffer[64];

// ============================================
// FARBEN
// ============================================
// TFT_ORANGE ist bereits in TFT_eSPI.h definiert (0xFDA0) - kein Redefine nötig
#define TFT_DARKERGREY 0x4208

// ============================================
// DISPLAY BEREICHE
// ============================================
#define SCHAUFEL_BTN_X 5
#define SCHAUFEL_BTN_Y 5
#define SCHAUFEL_BTN_W 220
#define SCHAUFEL_BTN_H 35

#define ADD2_Y 50
#define ADD2_H 100

#define BTN1_X 20
#define BTN1_Y 180
#define BTN2_X 170
#define BTN2_Y 180
#define BTN_W 130
#define BTN_H 50

// ============================================
// STATUS VARIABLEN - ADD2 Waage
// ============================================
int add2Gewicht = 0;
int add2AnzeigeGewicht = 0;
int add2Offset = 0;
bool add2ZeroModus = false;
bool add2DatenVorhanden = false;
bool add2WaageOff = false;  // Waage ist ausgeschaltet
unsigned long add2LastData = 0;

// ============================================
// WATCHDOG
// ============================================
#define WATCHDOG_TIMEOUT_SEC 5

// ============================================
// STATUS VARIABLEN - WiFi
// ============================================
enum WifiStatus { WIFI_OK, WIFI_SUCHE, WIFI_FEHLER };
WifiStatus wifiStatus = WIFI_SUCHE;
unsigned long lastReconnect = 0;
const int TIMEOUT_MS = 2000;
const int RECONNECT_INTERVAL = 5000;

// Signal-Bars (NEU v1.0.2)
int signalBars = 0;
unsigned long lastRSSIRead = 0;
const int RSSI_INTERVAL = 1000;  // 1 Hz Polling

// ============================================
// STATUS VARIABLEN - Schaufel
// ============================================
float schaufelRohwert = 0;
int schaufelGewicht = 0;
int schaufelGewichtGefiltert = 0;  // Nach Filter
bool schaufelInPosition = false;
float schaufelTara = 0;
float schaufelFaktor = 1.0;
unsigned long lastADCRead = 0;
bool adsVorhanden = false;  // ADS1115 gefunden?
const int ADC_INTERVAL = 100;  // 10Hz

// ADS1115-Watchdog (NEU v1.0.1)
int adsFehlerZaehler = 0;
const int ADS_FEHLER_LIMIT = 10;  // Nach 10 Fehlern: ADS als ausgefallen markieren
int16_t adsLetzterRawWert = 0;
int adsGleicheWerteZaehler = 0;
const int ADS_STUCK_LIMIT = 50;   // 50 identische Werte (~5 Sek) = hängt

// ============================================
// FILTER
// ============================================
#define FILTER_BUFFER_SIZE 30
float filterBuffer[FILTER_BUFFER_SIZE];
int filterBufferIndex = 0;
int filterBufferCount = 0;
int filterAnzahl = 10;      // Mittelwert über X Werte (5-30)
int filterSchwelle = 5;     // Hysterese in kg (1-10)
int letzteAngezeigtesGewicht = 0;

// ============================================
// MENÜ SYSTEM
// ============================================
enum MenuState { 
  MENU_NONE,
  MENU_SCHAUFEL,
  MENU_KALIBRIEREN,
  MENU_CONFIRM_TARA,
  MENU_FILTER
};
MenuState menuState = MENU_NONE;
int kalibierGewicht = 100;

// Temporäre Werte für Filter-Menü
int tempFilterAnzahl = 10;
int tempFilterSchwelle = 5;

// ============================================
// DISPLAY UPDATE FLAGS
// ============================================
bool displayNeedsFullRedraw = true;
int lastAdd2Anzeige = -99999;
bool lastAdd2DatenStatus = false;
WifiStatus lastWifiStatus = WIFI_SUCHE;
int lastSchaufelGewicht = -99999;
bool lastSchaufelPosition = false;
bool lastButtonsEnabled = false;
bool lastWaageOff = false;  // (v1.0.1: aus updateHauptbildschirm rausgezogen)
int lastSignalBars = -1;    // (NEU v1.0.2)

// ============================================
// HILFSFUNKTIONEN (NEU v1.0.1)
// ============================================

// Filter-Buffer komplett zurücksetzen
void resetFilter() {
  for (int i = 0; i < FILTER_BUFFER_SIZE; i++) {
    filterBuffer[i] = 0;
  }
  filterBufferIndex = 0;
  filterBufferCount = 0;
  letzteAngezeigtesGewicht = 0;
  schaufelGewichtGefiltert = 0;
}

// ZERO-Modus zurücksetzen (z.B. bei OFF oder Reconnect)
void resetZero() {
  if (add2ZeroModus) {
    Serial.println("[INFO] ZERO automatisch zurueckgesetzt");
    add2ZeroModus = false;
    add2Offset = 0;
  }
}

// ============================================
// SETUP
// ============================================
void setup() {
  Serial.begin(115200);
  delay(1000);
  
  Serial.println();
  Serial.println("========================================");
  Serial.println("ADD2go Empfaenger - v1.0.2");
  Serial.println("========================================");
  Serial.println();
  
  // Reed-Kontakt Pin
  pinMode(REED_SENSOR_PIN, INPUT);
  Serial.println("[OK] Reed-Kontakt GPIO36 konfiguriert");
  
  // I2C für ADS1115
  Wire.begin(21, 22);
  if (ads.begin()) {
    Serial.println("[OK] ADS1115 gefunden");
    ads.setGain(GAIN_ONE);
    adsVorhanden = true;
  } else {
    Serial.println("[FEHLER] ADS1115 nicht gefunden!");
    adsVorhanden = false;
  }
  
  // NVS laden
  prefs.begin("schaufel", false);
  schaufelTara = prefs.getFloat("tara", 0.0);
  schaufelFaktor = prefs.getFloat("faktor", 100.0);
  filterAnzahl = prefs.getInt("filterAnz", 10);
  filterSchwelle = prefs.getInt("filterSchw", 5);
  
  // Grenzen prüfen
  if (filterAnzahl < 5) filterAnzahl = 5;
  if (filterAnzahl > 30) filterAnzahl = 30;
  if (filterSchwelle < 1) filterSchwelle = 1;
  if (filterSchwelle > 10) filterSchwelle = 10;
  
  Serial.print("[OK] NVS geladen - Tara: ");
  Serial.print(schaufelTara, 3);
  Serial.print("V, Faktor: ");
  Serial.print(schaufelFaktor, 1);
  Serial.print(" kg/V, Filter: ");
  Serial.print(filterAnzahl);
  Serial.print(" Werte, Schwelle: ");
  Serial.print(filterSchwelle);
  Serial.println(" kg");
  
  // Filter-Buffer initialisieren
  resetFilter();  // (v1.0.1: über Hilfsfunktion)
  
  // Display
  tft.init();
  tft.setRotation(1);
  tft.fillScreen(TFT_BLACK);
  Serial.println("[OK] Display initialisiert");
  
  // Touch
  ts.begin();
  ts.setRotation(1);
  Serial.println("[OK] Touch initialisiert");
  
  // ========================================
  // BOOT-SCREEN MIT FORTSCHRITTSBALKEN
  // ========================================
  
  // Titel "ADD2go" - groß und zentriert
  tft.setFreeFont(&FreeSansBold18pt7b);
  tft.setTextColor(TFT_WHITE);
  String titel = "ADD2go";
  int titelW = tft.textWidth(titel);
  tft.setCursor((320 - titelW) / 2, 50);
  tft.print(titel);
  tft.setFreeFont(NULL);
  
  // Fortschrittsbalken - volle Breite mit kleinem Rand
  int barX = 15;
  int barY = 100;
  int barW = 290;  // 320 - 2*15
  int barH = 25;
  tft.drawRoundRect(barX, barY, barW, barH, 5, TFT_WHITE);
  
  // Status Y-Position (linksbündig mit Balken)
  int statusY = barY + barH + 15;
  
  // Hilfsfunktion inline - Fortschritt zeichnen
  auto zeichneProgress = [&](int prozent, const char* text) {
    // Balken füllen (grün)
    int fillW = (barW - 4) * prozent / 100;
    tft.fillRoundRect(barX + 2, barY + 2, fillW, barH - 4, 3, TFT_GREEN);
    
    // Status Text linksbündig unter Balken
    tft.fillRect(barX, statusY - 5, barW, 20, TFT_BLACK);
    tft.setTextColor(TFT_LIGHTGREY);
    tft.setTextSize(1);
    tft.setCursor(barX, statusY);
    tft.print(text);
    
    delay(200);
  };
  
  zeichneProgress(20, "Display OK");
  
  zeichneProgress(40, "Touch OK");
  
  // Watchdog konfigurieren (5 Sekunden) - VOR WiFi!
  esp_task_wdt_config_t wdt_config = {
    .timeout_ms = WATCHDOG_TIMEOUT_SEC * 1000,
    .idle_core_mask = (1 << 0) | (1 << 1),
    .trigger_panic = true
  };
  esp_err_t wdt_err = esp_task_wdt_init(&wdt_config);
  if (wdt_err == ESP_OK || wdt_err == ESP_ERR_INVALID_STATE) {
    esp_task_wdt_add(NULL);
    Serial.print("[OK] Watchdog: ");
    Serial.print(WATCHDOG_TIMEOUT_SEC);
    Serial.println(" Sekunden");
  }
  
  zeichneProgress(60, "Watchdog OK");
  
  // WiFi (Watchdog wird gefüttert in verbindeWiFi)
  zeichneProgress(80, "WiFi verbinden...");
  verbindeWiFi();
  
  if (WiFi.status() == WL_CONNECTED) {
    zeichneProgress(100, "WiFi OK!");
  } else {
    // Balken orange bei Fehler
    tft.fillRoundRect(barX + 2, barY + 2, barW - 4, barH - 4, 3, TFT_ORANGE);
    tft.fillRect(barX, statusY - 5, barW, 20, TFT_BLACK);
    tft.setTextColor(TFT_ORANGE);
    tft.setCursor(barX, statusY);
    tft.print("WiFi nicht gefunden...");
  }
  
  // Copyright - klein und zentriert
  delay(300);
  tft.setTextColor(TFT_DARKGREY);
  tft.setTextSize(1);
  String copyright = "(c) MST 2026 - v1.0.2";
  int copyW = tft.textWidth(copyright);
  tft.setCursor((320 - copyW) / 2, 200);
  tft.print(copyright);
  
  delay(800);
  
  // UI zeichnen
  displayNeedsFullRedraw = true;
  
  Serial.println();
  Serial.println("System bereit!");
  Serial.println();
}

// ============================================
// MAIN LOOP
// ============================================
void loop() {
  // Watchdog füttern
  esp_task_wdt_reset();
  
  // 1. Reed-Kontakt SOFORT lesen (schnelle Reaktion!)
  schaufelInPosition = (digitalRead(REED_SENSOR_PIN) == LOW);
  
  // 2. WiFi managen
  handleWiFi();
  
  // 3. UDP Daten empfangen
  handleUDP();
  
  // 4. ADS1115 lesen (alle 100ms = 10Hz)
  handleADC();

  // 4b. RSSI lesen (alle 1s)
  handleRSSI();

  // 5. Touch verarbeiten
  handleTouch();
  
  // 6. Display aktualisieren
  handleDisplay();
  
  // 7. Im Menü: Live-Update
  handleMenuLiveUpdate();
  
  delay(10);
}

// ============================================
// WIFI HANDLING
// ============================================
void handleWiFi() {
  // Watchdog füttern bei WiFi-Problemen
  esp_task_wdt_reset();
  
  if (WiFi.status() != WL_CONNECTED) {
    if (wifiStatus == WIFI_OK) {
      Serial.println("[WARNUNG] WiFi Verbindung verloren!");
      wifiStatus = WIFI_FEHLER;
      lastReconnect = millis();
      // (v1.0.1) ZERO zurücksetzen wenn Verbindung weg
      resetZero();
    } 
    else if (millis() - lastReconnect > RECONNECT_INTERVAL) {
      // Nicht-blockierender Reconnect
      Serial.println("[INFO] Starte Reconnect...");
      wifiStatus = WIFI_SUCHE;
      WiFi.disconnect(true);  // true = WiFi auch abschalten
      delay(100);             // Kurz warten
      WiFi.begin(WIFI_SSID, WIFI_PASS);
      lastReconnect = millis();
    }
  } else {
    if (wifiStatus != WIFI_OK) {
      wifiStatus = WIFI_OK;
      Serial.print("[OK] WiFi verbunden! IP: ");
      Serial.println(WiFi.localIP());
      udp.stop();
      udp.begin(UDP_PORT);
    }
  }
}

void verbindeWiFi() {
  Serial.print("Verbinde mit ");
  Serial.print(WIFI_SSID);
  Serial.print("...");
  
  WiFi.mode(WIFI_STA);
  WiFi.begin(WIFI_SSID, WIFI_PASS);
  
  int versuche = 0;
  while (WiFi.status() != WL_CONNECTED && versuche < 10) {
    esp_task_wdt_reset();  // Watchdog füttern während wir warten!
    delay(500);
    Serial.print(".");
    versuche++;
  }
  Serial.println();
  
  if (WiFi.status() == WL_CONNECTED) {
    Serial.print("[OK] Verbunden! IP: ");
    Serial.println(WiFi.localIP());
    udp.stop();
    udp.begin(UDP_PORT);
  } else {
    Serial.println("[FEHLER] Verbindung fehlgeschlagen");
  }
}

// ============================================
// UDP HANDLING
// ============================================
void handleUDP() {
  if (WiFi.status() != WL_CONNECTED) return;
  
  int packetSize = udp.parsePacket();
  if (packetSize > 0) {
    int len = udp.read(udpBuffer, sizeof(udpBuffer) - 1);
    if (len > 0) {
      udpBuffer[len] = '\0';
      
      // Prüfen ob "OFF" empfangen
      if (strcmp(udpBuffer, "OFF") == 0) {
        // (v1.0.1) Beim Übergang ON->OFF: ZERO zurücksetzen
        if (!add2WaageOff) {
          resetZero();
        }
        add2WaageOff = true;
        add2DatenVorhanden = true;  // Verbindung ist da, nur Waage aus
        add2LastData = millis();
      } else {
        add2WaageOff = false;
        add2Gewicht = atoi(udpBuffer);
        add2DatenVorhanden = true;
        add2LastData = millis();
      }
    }
  }
  
  // Timeout prüfen (keine UDP Pakete mehr)
  if (add2DatenVorhanden && (millis() - add2LastData > TIMEOUT_MS)) {
    add2DatenVorhanden = false;
    add2WaageOff = false;
    // (v1.0.1) ZERO zurücksetzen bei Daten-Timeout
    resetZero();
    Serial.println("[WARNUNG] ADD2 Daten-Timeout");
  }
}

// ============================================
// ADC HANDLING MIT FILTER
// ============================================
void handleADC() {
  // Nur wenn ADS1115 vorhanden!
  if (!adsVorhanden) return;
  
  if (millis() - lastADCRead < ADC_INTERVAL) return;
  lastADCRead = millis();
  
  // ADC lesen
  int16_t rawADC = ads.readADC_SingleEnded(0);
  
  // (v1.0.1) ADS1115-Watchdog: erkenne hängenden oder defekten Sensor
  // Fehlerwerte: -1 oder konstant 0 / max bei nicht angeschlossenem Sensor
  if (rawADC == -1) {
    adsFehlerZaehler++;
    if (adsFehlerZaehler >= ADS_FEHLER_LIMIT) {
      Serial.println("[FEHLER] ADS1115 liefert Fehlerwerte - als ausgefallen markiert");
      adsVorhanden = false;
      adsFehlerZaehler = 0;
    }
    return;
  } else {
    adsFehlerZaehler = 0;
  }
  
  // Hängender Wert? (z.B. I2C-Bus eingefroren)
  if (rawADC == adsLetzterRawWert) {
    adsGleicheWerteZaehler++;
    if (adsGleicheWerteZaehler >= ADS_STUCK_LIMIT) {
      Serial.println("[FEHLER] ADS1115 haengt - als ausgefallen markiert");
      adsVorhanden = false;
      adsGleicheWerteZaehler = 0;
      return;
    }
  } else {
    adsGleicheWerteZaehler = 0;
    adsLetzterRawWert = rawADC;
  }
  
  schaufelRohwert = rawADC * 0.000125;
  
  if (schaufelInPosition) {
    // Rohgewicht berechnen
    float spannungBereinigt = schaufelRohwert - schaufelTara;
    schaufelGewicht = (int)(spannungBereinigt * schaufelFaktor);
    if (schaufelGewicht < 0) schaufelGewicht = 0;
    
    // In Filter-Buffer speichern
    filterBuffer[filterBufferIndex] = schaufelGewicht;
    filterBufferIndex = (filterBufferIndex + 1) % FILTER_BUFFER_SIZE;
    if (filterBufferCount < FILTER_BUFFER_SIZE) filterBufferCount++;
    
    // Mittelwert berechnen (über filterAnzahl Werte)
    float summe = 0;
    int anzahl = min(filterAnzahl, filterBufferCount);
    for (int i = 0; i < anzahl; i++) {
      int idx = (filterBufferIndex - 1 - i + FILTER_BUFFER_SIZE) % FILTER_BUFFER_SIZE;
      summe += filterBuffer[idx];
    }
    int mittelwert = (int)(summe / anzahl);
    
    // Hysterese anwenden
    if (abs(mittelwert - letzteAngezeigtesGewicht) >= filterSchwelle) {
      schaufelGewichtGefiltert = mittelwert;
      letzteAngezeigtesGewicht = mittelwert;
    }
    // Sonst bleibt schaufelGewichtGefiltert unverändert
  }
}

// ============================================
// RSSI HANDLING (NEU v1.0.2)
// ============================================
void handleRSSI() {
  if (millis() - lastRSSIRead < RSSI_INTERVAL) return;
  lastRSSIRead = millis();

  if (WiFi.status() == WL_CONNECTED) {
    int8_t rssi = WiFi.RSSI();
    signalBars = rssi > -50 ? 4 : rssi > -60 ? 3 : rssi > -70 ? 2 : rssi > -80 ? 1 : 0;
  } else {
    signalBars = 0;
  }
}

// ============================================
// MENÜ LIVE UPDATE
// ============================================
void handleMenuLiveUpdate() {
  if (menuState == MENU_NONE) return;
  
  static bool letztePositionImMenu = true;
  
  if (schaufelInPosition != letztePositionImMenu) {
    letztePositionImMenu = schaufelInPosition;
    
    Serial.print("[INFO] Wiegeposition geändert: ");
    Serial.println(schaufelInPosition ? "JA" : "NEIN");
    
    displayNeedsFullRedraw = true;
    
    if (!schaufelInPosition && (menuState == MENU_KALIBRIEREN || menuState == MENU_CONFIRM_TARA)) {
      Serial.println("[WARNUNG] Position verloren - zurück zum Menü");
      menuState = MENU_SCHAUFEL;
    }
  }
}

// ============================================
// TOUCH HANDLING
// ============================================
void handleTouch() {
  if (!ts.touched()) return;
  
  TS_Point p = ts.getPoint();
  int tx = map(p.x, 3900, 300, 0, 320);
  int ty = map(p.y, 3900, 300, 0, 240);
  
  delay(50);
  
  switch (menuState) {
    case MENU_NONE:
      handleTouchHauptbildschirm(tx, ty);
      break;
    case MENU_SCHAUFEL:
      handleTouchSchaufelMenu(tx, ty);
      break;
    case MENU_KALIBRIEREN:
      handleTouchKalibrieren(tx, ty);
      break;
    case MENU_CONFIRM_TARA:
      handleTouchTaraConfirm(tx, ty);
      break;
    case MENU_FILTER:
      handleTouchFilter(tx, ty);
      break;
  }
  
  delay(150);
}

void handleTouchHauptbildschirm(int tx, int ty) {
  // Schaufel-Button oben?
  if (tx >= SCHAUFEL_BTN_X && tx <= SCHAUFEL_BTN_X + SCHAUFEL_BTN_W &&
      ty >= SCHAUFEL_BTN_Y && ty <= SCHAUFEL_BTN_Y + SCHAUFEL_BTN_H) {
    Serial.println(">>> Schaufel-Button gedrückt");
    menuState = MENU_SCHAUFEL;
    displayNeedsFullRedraw = true;
    return;
  }
  
  // Untere Buttons nur wenn ADD2 Daten vorhanden UND Waage nicht OFF
  if (!add2DatenVorhanden || add2WaageOff) {
    // Nur loggen wenn auf Button-Bereich gedrückt wurde
    if (ty >= BTN1_Y && ty <= BTN1_Y + BTN_H) {
      Serial.println("[INFO] Buttons deaktiviert - keine Daten oder Waage OFF");
    }
    return;
  }
  
  // TOTAL Button
  if (tx >= BTN1_X && tx <= BTN1_X + BTN_W &&
      ty >= BTN1_Y && ty <= BTN1_Y + BTN_H) {
    Serial.println(">>> TOTAL gedrückt");
    add2ZeroModus = false;
    add2Offset = 0;
    displayNeedsFullRedraw = true;
  }
  
  // ZERO Button
  if (tx >= BTN2_X && tx <= BTN2_X + BTN_W &&
      ty >= BTN2_Y && ty <= BTN2_Y + BTN_H) {
    Serial.println(">>> ZERO gedrückt");
    add2ZeroModus = true;
    add2Offset = add2Gewicht;
    Serial.print("Offset gesetzt: ");
    Serial.println(add2Offset);
    displayNeedsFullRedraw = true;
  }
}

void handleTouchSchaufelMenu(int tx, int ty) {
  // TARA Button (y: 50-85)
  if (ty >= 50 && ty <= 85 && tx >= 40 && tx <= 280) {
    Serial.println(">>> TARA gewählt");
    if (schaufelInPosition) {
      menuState = MENU_CONFIRM_TARA;
      displayNeedsFullRedraw = true;
    } else {
      Serial.println("[INFO] Nicht in Wiegeposition!");
    }
    return;
  }
  
  // KALIBRIEREN Button (y: 95-130)
  if (ty >= 95 && ty <= 130 && tx >= 40 && tx <= 280) {
    Serial.println(">>> KALIBRIEREN gewählt");
    if (schaufelInPosition) {
      kalibierGewicht = 100;
      menuState = MENU_KALIBRIEREN;
      displayNeedsFullRedraw = true;
    } else {
      Serial.println("[INFO] Nicht in Wiegeposition!");
    }
    return;
  }
  
  // FILTER Button (y: 140-175)
  if (ty >= 140 && ty <= 175 && tx >= 40 && tx <= 280) {
    Serial.println(">>> FILTER gewählt");
    tempFilterAnzahl = filterAnzahl;
    tempFilterSchwelle = filterSchwelle;
    menuState = MENU_FILTER;
    displayNeedsFullRedraw = true;
    return;
  }
  
  // ZURÜCK Button (y: 185-220)
  if (ty >= 185 && ty <= 220 && tx >= 40 && tx <= 280) {
    Serial.println(">>> ZURÜCK gewählt");
    menuState = MENU_NONE;
    displayNeedsFullRedraw = true;
    return;
  }
}
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

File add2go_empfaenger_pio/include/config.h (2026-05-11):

// add2go-empfaenger-pio config.h
// Pin-Defines + Konstanten (zentral). 1:1 aus add2go_empfaenger_v1_0_2.ino
// uebernommen, plus Phase-3c-Erweiterungen.

#pragma once

#include <stdint.h>

// ---- Hardware Pins ----
#define REED_SENSOR_PIN     36   // Reed-Kontakt fuer Wiegeposition (LOW = drauf)
#define I2C_SDA             21
#define I2C_SCL             22
// TFT-Pins + TOUCH_CS werden via build_flags an TFT_eSPI uebergeben (siehe platformio.ini).
// TOUCH_CS_PIN brauchen wir aber als Compile-Zeit-Konstante fuer XPT2046_Touchscreen-Konstruktor.
#define TOUCH_CS_PIN        15
#define TOUCH_IRQ           14

// ---- Watchdog ----
#define WATCHDOG_TIMEOUT_SEC  5

// ---- WiFi ----
#define WIFI_AP_ADD2GO       "ADD2go"
#define WIFI_AP_ADD2FLOW     "add2flow"
#define WIFI_RECONNECT_INTERVAL_MS  5000
#define WIFI_STA_SWITCH_TIMEOUT_MS  5000   // Phase 3c: Tab-Switch Fallback-Screen nach 5 s

// ---- UDP (add2go-Sender) ----
#define UDP_PORT_ADD2GO     5005
#define UDP_BUFFER_SIZE     64

// ---- ADC / Schaufel ----
#define ADC_INTERVAL_MS     100   // 10 Hz
#define ADS_FEHLER_LIMIT    10    // 10 I2C-Fehler -> Sensor-Fehler
#define ADS_STUCK_LIMIT     50    // 50 identische Werte -> stuck

// ---- Filter ----
#define FILTER_BUFFER_SIZE  30
#define FILTER_ANZAHL_DEFAULT  10
#define FILTER_ANZAHL_MIN   5
#define FILTER_ANZAHL_MAX   30
#define FILTER_SCHWELLE_DEFAULT  5
#define FILTER_SCHWELLE_MIN  1
#define FILTER_SCHWELLE_MAX  10

// ---- RSSI / Signal-Bars ----
#define RSSI_INTERVAL_MS    1000  // 1 Hz Polling

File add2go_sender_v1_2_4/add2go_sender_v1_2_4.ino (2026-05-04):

/*
 * ADD2go Sender - v1.2.4
 * ======================
 * 
 * Wireless Brücke für Dinamica Generale ADD2 Waage
 * Liest Gewichtsdaten via RS232 und sendet per WiFi/UDP + WebSocket
 * 
 * NEU in v1.2.4:
 * - Fix: WDT-Reset in Boot-Warteschleife
 * - Fix: idle_core_mask konservativer (nur loopTask)
 * - Fix: JSON SSID Escaping
 * 
 * NEU in v1.2.3:
 * - PWA Support: Als App installierbar
 * - Manifest + Icons für Startbildschirm
 * - Install-Banner in WebApp
 * 
 * NEU in v1.2.2:
 * - mDNS: Erreichbar unter http://add2go.local
 * - Warten auf WLAN-Verbindung beim Boot
 * - Bessere NVS Debug-Ausgaben
 * 
 * NEU in v1.2.1:
 * - Async WLAN-Scan (verhindert WDT-Trigger)
 * - Robustere loop() mit mehrfachen WDT-Resets
 * - WDT-Init mit Fehlerprüfung
 * - RS232 Byte-Limit pro loop()
 * - delay(1) für WiFi/TCP Stack
 * 
 * NEU in v1.2:
 * - WiFi-Manager WebUI unter /setup
 * - WLAN scannen und verbinden
 * - Einstellungen werden gespeichert (NVS)
 * - APSTA Modus: AP + Station gleichzeitig
 * - Erreichbar über ADD2go-WLAN UND Hof-WLAN
 * 
 * Features v1.1:
 * - WebSocket Server für Browser/Handy
 * - Eingebettete WebApp unter http://192.168.4.1
 * - Signalstärke-Anzeige
 * - Parallelbetrieb: Hardware-Empfänger + Handy gleichzeitig
 * 
 * Features v1.0:
 * - WiFi Access Point "ADD2go" (Empfänger verbindet sich)
 * - RS232 Empfang mit Frame-Parsing
 * - UDP Broadcast alle 100ms (10 Hz) -> Hardware-Empfänger
 * - Hardware Watchdog (10 Sekunden)
 * - "OFF" senden wenn Waage aus (3 Sek Timeout)
 * 
 * Benötigte Library:
 * - WebSockets by Markus Sattler (Arduino Library Manager)
 * 
 * (c) MST 2026
 */

#include <WiFi.h>
#include <WiFiUdp.h>
#include <WebServer.h>
#include <WebSocketsServer.h>
#include <Preferences.h>
#include <ESPmDNS.h>
#include <esp_task_wdt.h>
#include <esp_wifi.h>

// ============================================
// KONFIGURATION
// ============================================

// WiFi Access Point (immer aktiv)
const char* AP_SSID = "ADD2go";
const char* AP_PASS = "";  // Offen, kein Passwort

// mDNS Hostname (erreichbar unter add2go.local)
const char* MDNS_HOSTNAME = "add2go";

// UDP (für Hardware-Empfänger)
const int UDP_PORT = 5005;
IPAddress broadcastIP(192, 168, 4, 255);
WiFiUDP udp;

// WebServer + WebSocket (für Handy/Browser)
WebServer server(80);
WebSocketsServer webSocket(81);

// Preferences für WLAN-Speicherung
Preferences preferences;

// RS232 Pins
#define RXD2 16
#define TXD2 17

// Timing
#define SEND_INTERVAL 100       // UDP/WebSocket senden alle 100ms (10 Hz)
#define WAAGE_TIMEOUT 3000      // Nach 3 Sek ohne Daten = "OFF"
#define WATCHDOG_TIMEOUT_SEC 10 // Watchdog 10 Sekunden
#define AP_CHECK_INTERVAL 30000 // AP alle 30 Sekunden prüfen
#define STA_RETRY_INTERVAL 30000 // Station Reconnect alle 30 Sek
#define WIFI_CONNECT_TIMEOUT 10000 // 10 Sek Timeout beim Verbinden

// WebSocket
#define MAX_WS_CLIENTS 4        // Maximal 4 Browser gleichzeitig

// ============================================
// VARIABLEN
// ============================================

// Buffer für RS232
#define BUFFER_SIZE 64
uint8_t buffer[BUFFER_SIZE];
int bufferIndex = 0;
bool frameStarted = false;

// Gewicht
String aktuellesGewicht = "OFF";
unsigned long letzterEmpfang = 0;
bool waageOnline = false;

// Timing
unsigned long lastSendTime = 0;
unsigned long lastAPCheck = 0;
unsigned long lastSTARetry = 0;

// Station Mode (Verbindung zu externem WLAN)
String savedSSID = "";
String savedPassword = "";
bool staEnabled = false;
bool staConnected = false;
IPAddress staIP;

// Statistik
unsigned long frameCount = 0;
unsigned long sendCount = 0;

// Async WLAN-Scan
bool scanRunning = false;

// ============================================
// FORWARD DECLARATIONS
// ============================================
void handleRoot();
void handleSetup();
void handleManifest();
void handleIcon192();
void handleIcon512();
void handleApiStatus();
void handleApiScan();
void handleApiConnect();
void handleApiDisconnect();
void webSocketEvent(uint8_t num, WStype_t type, uint8_t * payload, size_t length);
int8_t getSignalRSSI();
void leseRS232();
void pruefeWaageTimeout();
void sendeUDP();
void sendeWebSocket();
void pruefeAP();
void verarbeiteFrame();
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

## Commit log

2026-05-05 User_Setup.h als Vorlage im Repo, README-Pfade korrigiert, CLAUDE.md ergänzt
    [User_Setup.h]
2026-05-05 Empfänger-STLs in case/ hinzugefügt, Sender-Gehäuse in README
    [Ball-joint_mit_bohrung.stl, Ball-joint_screwv1.3.stl, anschraubplatte_neu.stl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]
2026-05-05 Spannungsregler: 7805 → K7805M (Schaltregler)
2026-05-05 PCB-README mit Bildern hinzugefügt, kicad_prl-Cleanup
2026-05-05 case-README mit Schalter und Kabelverschraubung, Verlinkung in Haupt-README
2026-05-05 Empfänger v1.0.2: Signalstärke-Anzeige, SENSOR-FEHLER passt in Button
2026-05-05 Sender-Sketch: Ordner und Datei von _v1_2_4_1 auf _v1_2_4 umbenannt
2026-05-11 test: confirm hook -A flag stages deletions
2026-05-11 phase3c-4+5: tab-switch button + flow-tab with WebSocketsClient
    Schritt 4 — Tab-Switch-Button rechts oben (35x35), toggelt Schaufel <-> Flow.
    - Schaufel aktiv: dunkelblauer Wassertropfen (Ziel = Flow wechseln)
    - Flow aktiv: "ADD" / "2" zweizeilig rubinrot (Ziel = zurueck zu Schaufel)
    Schritt 5 — Flow-Tab mit WebSocketsClient zu add2flow.
    - flow_tab.{h,cpp}: WS-Logik, pipe-Parser (v1|STATE|done|target|lpm|preset|err|rssi|p1|p2|p3),
    State-Cache, Confirm-Modal-Logik, Touch-Routing.
    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
2026-05-11 phase3c-5: flow-tab selective redraw fix + presets without L
    - Flicker bei 10 Hz WS-Updates behoben: zeichneFlowTab macht jetzt full-draw nur bei Tab-Switch, updateFlowTab macht state-tracking + partial redraw pro Feld (Liter / L/min / Badge / Buttons).
    - Preset-Buttons zeigen nur Zahl (kein 'L'-Suffix) — passt fuer 3-stellige Liter-Werte in 70 px Buttons.
    [display.cpp]
2026-05-12 phase3c-7: ADD2-button stays visible during FILLING
    drawFlowLiters fillRect war 0..320 breit — ueberzeichnete dabei die untere
    Haelfte des Tab-Switch-Buttons (x=283..318, y=30..65). Bei jedem Liter-Update
    verschwand der Button-Bottom. Fix: fillRect bis x=280 statt 320 (Liter-Text
    zentriert auf 160 bleibt sicher in 0..280-Range).
    [display.cpp]
